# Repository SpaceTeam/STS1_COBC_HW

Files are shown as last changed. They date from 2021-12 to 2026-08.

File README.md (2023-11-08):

# COBC Hardware

This is a github repo for the COBC (communication and on-board computer) project of SpaceTeamSat1 (STS1) CubeSat mission of the TU Wien Space Team.

# Licensing
STS1_COBC_HW (c) by TU Wien Space Team

STS1_COBC_HW is licensed under a
Creative Commons Attribution 4.0 International License.

You should have received a copy of the license along with this
work. If not, see <https://creativecommons.org/licenses/by/4.0/>.

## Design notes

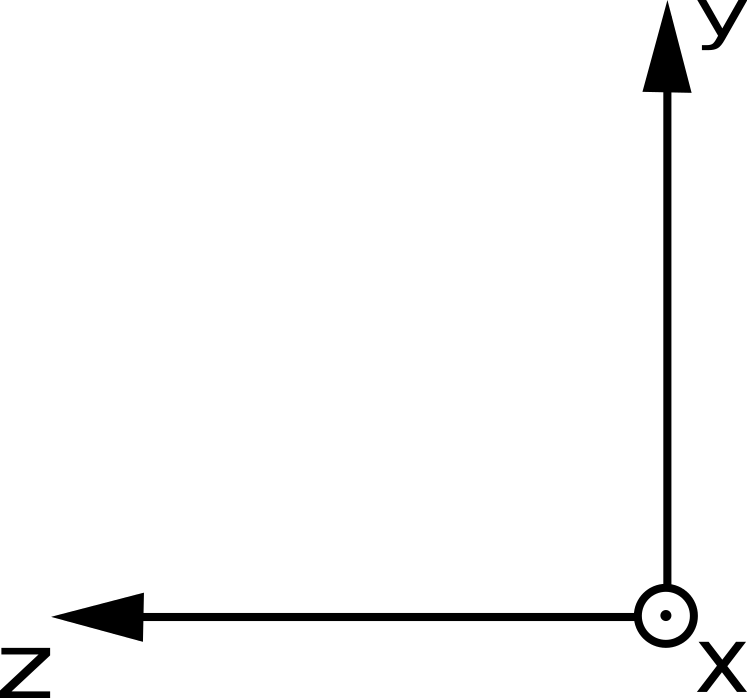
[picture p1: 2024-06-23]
coordinatesystem.png

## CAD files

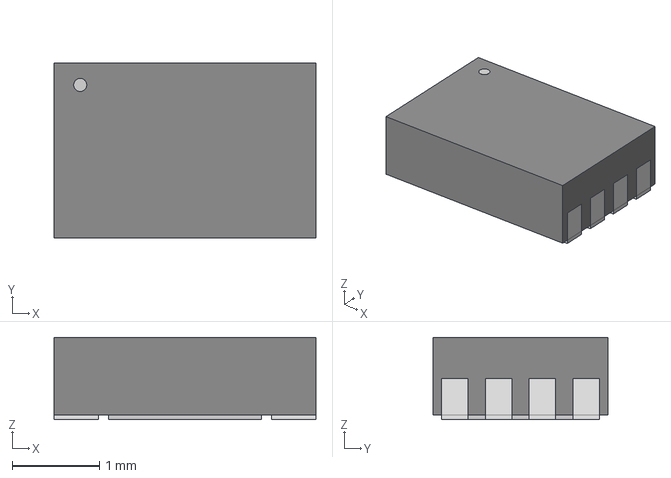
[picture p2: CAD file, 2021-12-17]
Parts/2021-11-17_15-36-51/STEP/DFN8_2x3MC_MCH.step
3.00 x 2.01 x 0.942 mm

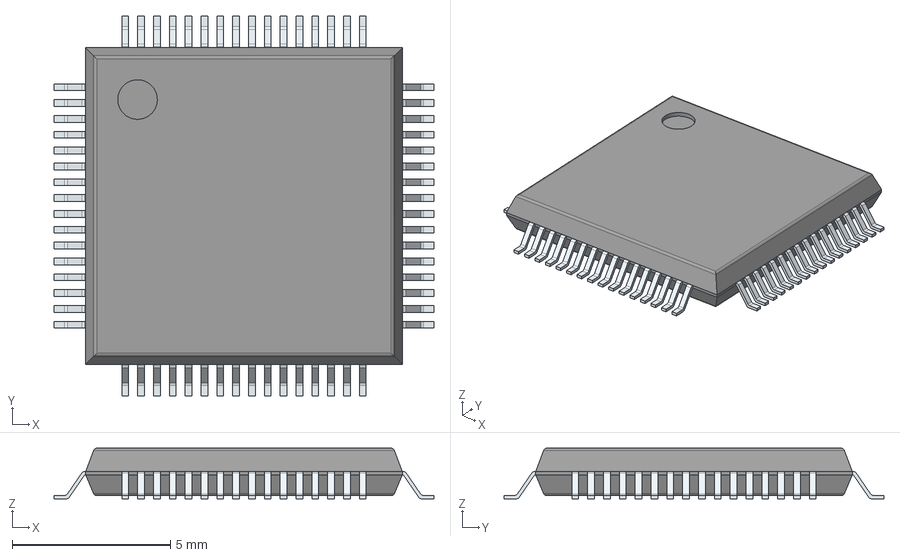
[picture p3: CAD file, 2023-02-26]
Parts/STM32F411RET6TR/3D/STM32F411RET6TR.stp
12.0 x 12.0 x 1.60 mm
PinsArrayLR
PinsArrayTB

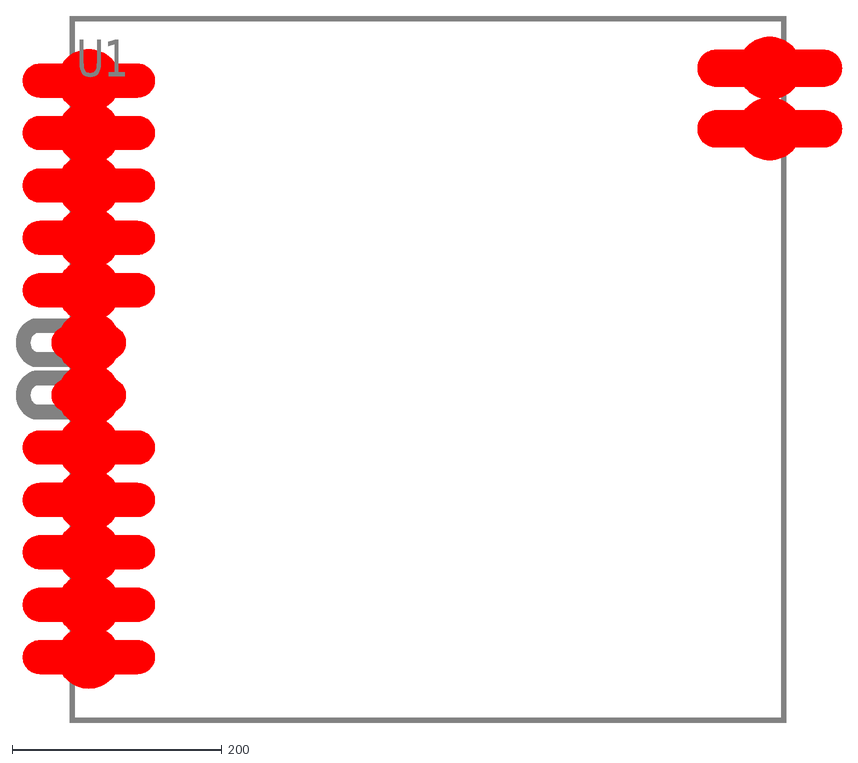
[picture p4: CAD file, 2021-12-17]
Parts/小功率封装.dxf
U1

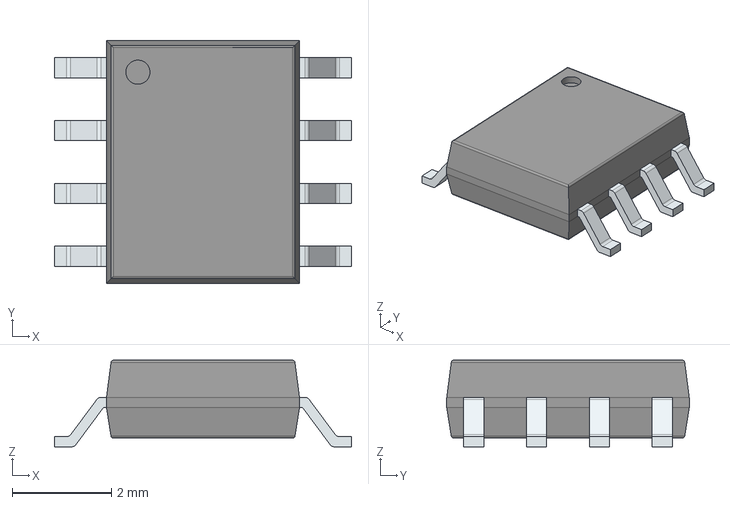
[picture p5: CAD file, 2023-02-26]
SpaceteamLib/MCP1725-3302E_SN/3D/MCP1725-3302E_SN.stp
6.00 x 4.90 x 1.75 mm
PinsArrayLR

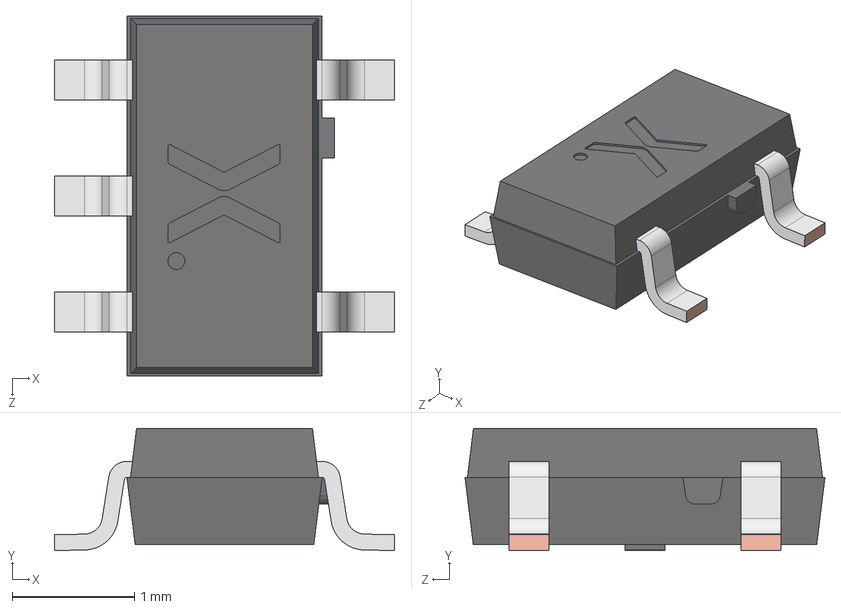
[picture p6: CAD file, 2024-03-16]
STSLib/74LVC1G32GV_125.stp
2.79 x 1.00 x 2.95 mm
SOT753 Lower mold body
SOT753 Lead x 5
SOT753 Upper mold body

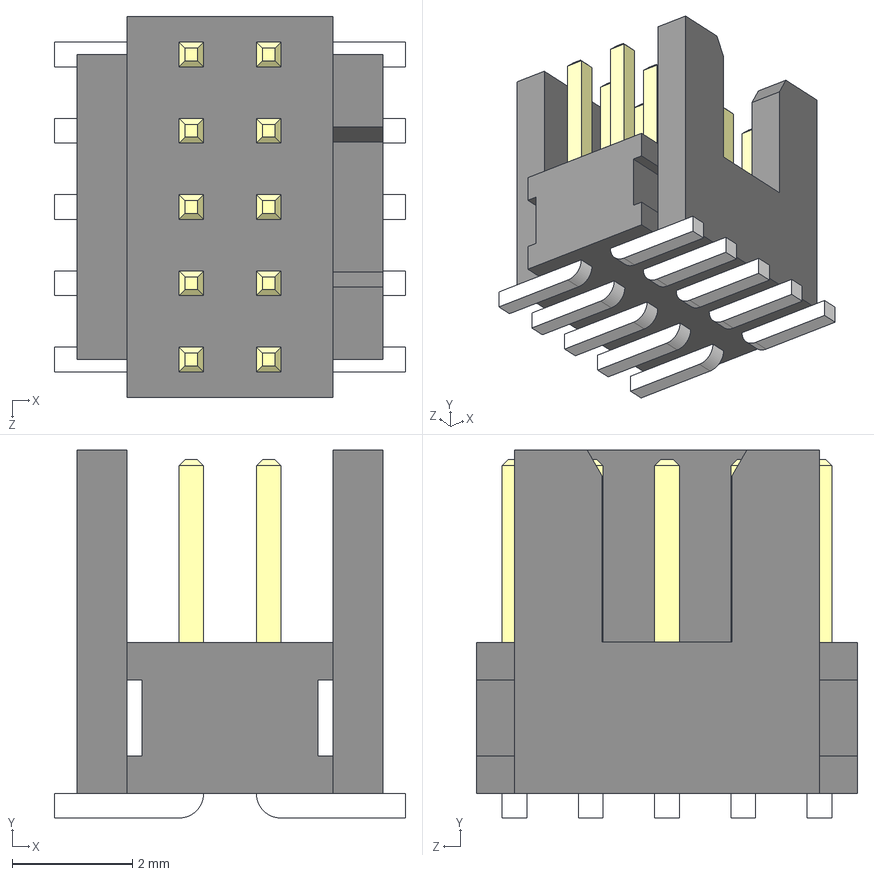
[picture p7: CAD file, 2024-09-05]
SWD-Adapter/3D-models/FTSH-105-01-L-DV-K.stp
5.85 x 6.13 x 6.35 mm

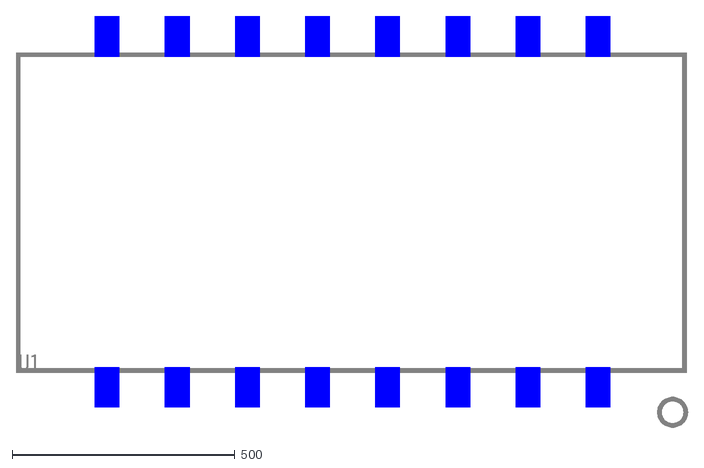
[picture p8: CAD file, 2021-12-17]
Parts/F27 F30 package 2018.dxf
U1

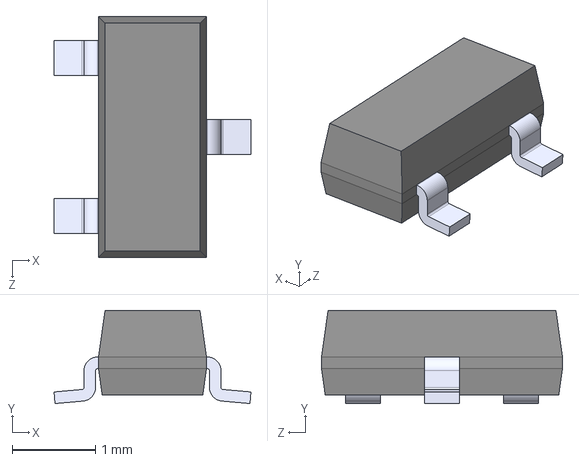
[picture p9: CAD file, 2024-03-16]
STSLib/MCP130T-300I_TT.step
2.37 x 1.12 x 2.90 mm

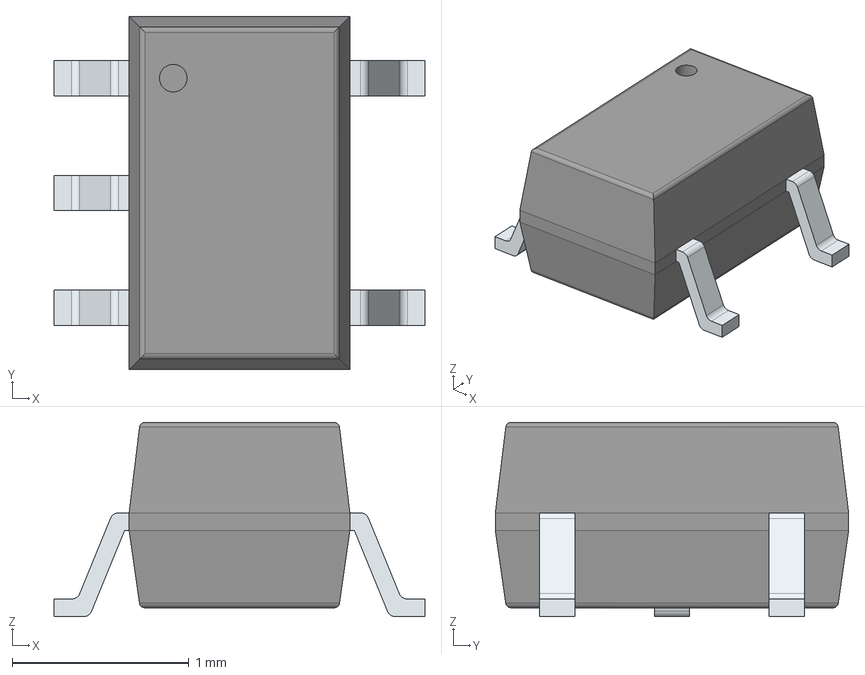
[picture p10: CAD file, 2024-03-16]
STSLib/NC7SZ32P5X-F22057.stp
2.10 x 2.00 x 1.10 mm
PinsArrayL
PinsArrayR

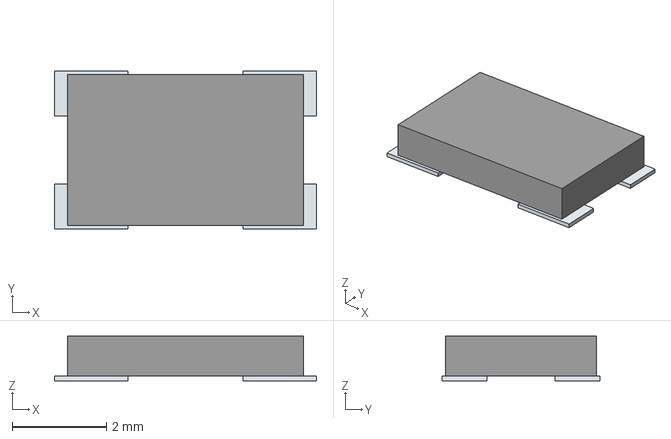
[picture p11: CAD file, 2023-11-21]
STSLib/405C35B12M00000.stp
5.56 x 3.36 x 0.95 mm
Pins

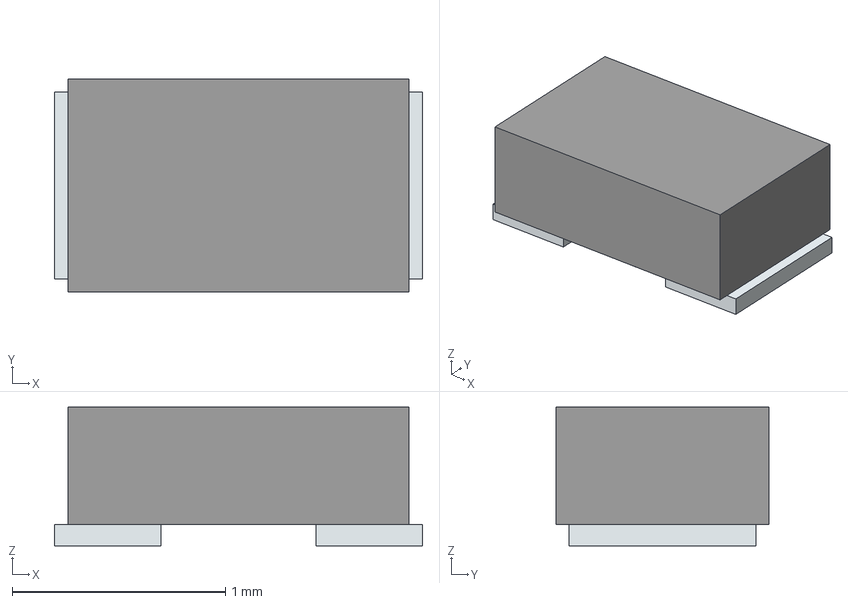
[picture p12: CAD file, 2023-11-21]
STSLib/UCLAMP0871P.TNT.stp
1.73 x 1.00 x 0.65 mm
Pins

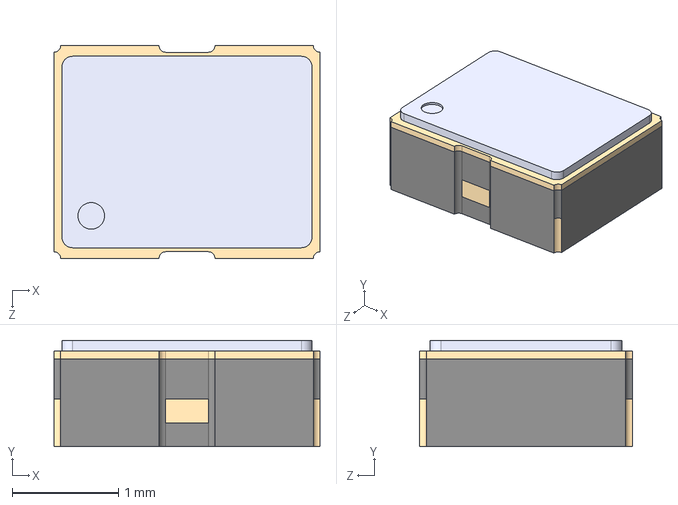
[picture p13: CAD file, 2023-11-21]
STSLib/ECS-2033-250-BN.step
2.50 x 1.00 x 2.00 mm

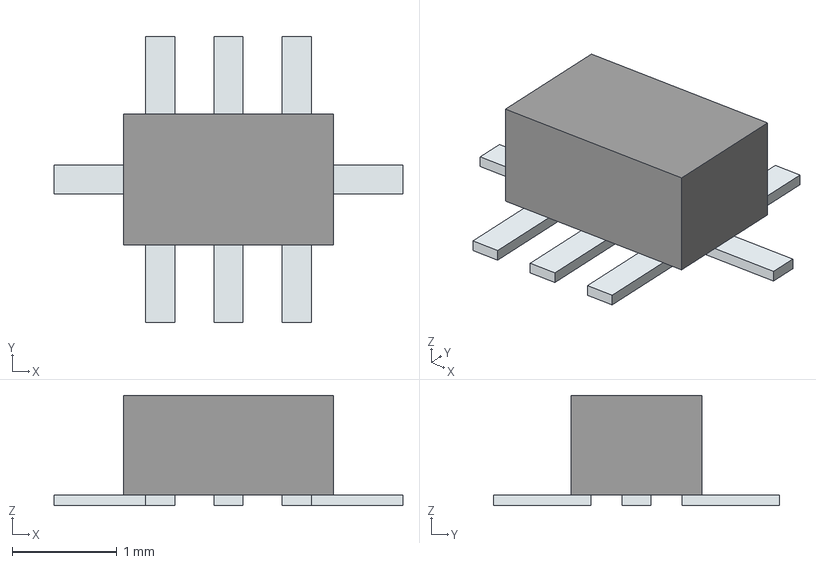
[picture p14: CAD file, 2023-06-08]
STSLib/LFCG-490+.stp
3.33 x 2.73 x 1.05 mm
Pins

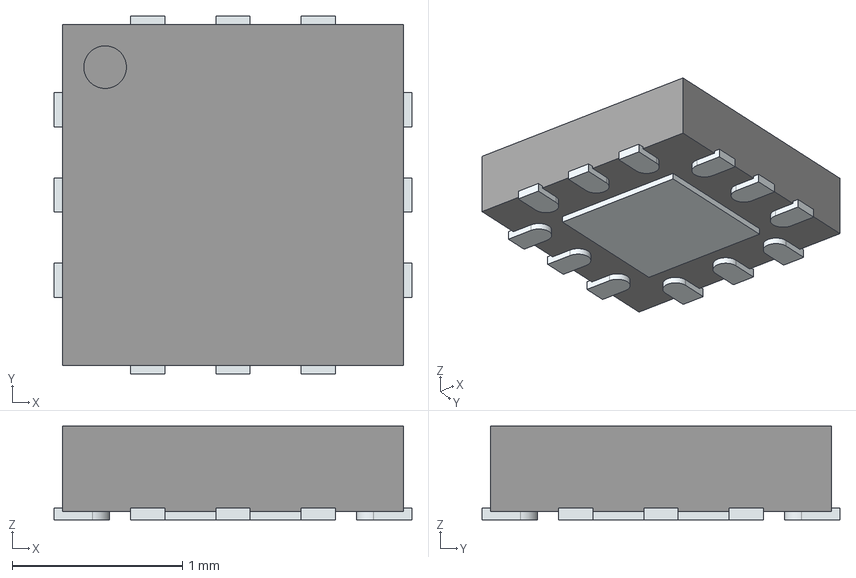
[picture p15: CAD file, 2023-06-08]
STSLib/F2972NEGK8.stp
2.10 x 2.10 x 0.55 mm
ThermalPin
PinsArrayLR
PinsArrayTB

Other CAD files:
Parts/si4463_Vc2/master/master.obj
Parts/si4463_Vc2/slaver/startup.obj
Parts/si4463_Vc2/master/startup.obj
Parts/si4463_Vc2/slaver/slaver.obj
Parts/STM32F411RET6TR/3D/STM32F411RET6TR.stl
Parts/STM32F411RET6TR/Allegro/qfp50p1200x1200x160-64n.psm
Parts/STM32F411RET6TR/DEHDL/stm32f411ret6tr/chips/chips.prt
STSLib/61612002121503.stp
STSLib/CY15B108QN-40SXI.stp
STSLib/FPF2701MPX.stp
STSLib/MC74HC4538ADG.stp
STSLib/MCP1725-3302E_MC.stp
STSLib/MP28167GQ-P.stp
STSLib/STM32F411RET6TR.stl
STSLib/Si4463-C2A-GM.stp
STSLib/TQP3M9036.stp
STSLib/W25Q01JVZEIQ.stp
SpaceteamLib/MCP1725-3302E_SN/3D/MCP1725-3302E_SN.stl
SpaceteamLib/MCP1725-3302E_SN/Allegro/soic127p600x175-8n.psm
SpaceteamLib/MCP1725-3302E_SN/DEHDL/mcp1725_3302e_sn/chips/chips.prt

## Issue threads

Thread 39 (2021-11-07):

add latch up protection for stm and rf modules

XDjackieXD, 2021-11-07:
we need separate latch up protection for the stm and the rf modules.
the stm should be able to disable said protection for the rf modules, as they draw *way* more power during transmit (so we disable their latch up protection during TX and enable it again after we are done sending)

asmolyanyuk, 2024-03-17:
Added two separate latch-up protection circuits.
The schematics employed is from the page 149 (164 pdf) of "Project solutions for low-cost space missions" [thesis](https://zerorobotics.polito.it/app/uploads/2019/04/thesis-1.pdf).

Closed 2024-03-17.

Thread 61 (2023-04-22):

RF temp sensor

WagnerDavid, 2023-04-22:
We should place a temperature sensor next to the RF chip, so we can figure out if something went wrong and react to it - send less or so

Jakob: "if you tell me at which adc input from the stm then gladly. I would just suggest the tmp36. it is low power, quite accurate and has a linear output." Analog as it is more reliable.

asmolyanyuk, 2024-03-17:
A temperature sensor is placed next to the RF chip, tmp36, and internal ADC of STM will be used to probe it (pin PC0).

Closed 2024-03-17.

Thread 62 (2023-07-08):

Add a separate 3.3 V LDO for RF part

asmolyanyuk, 2023-07-08:
We need to have a separate LDO on the 3.3 V rail of RF subsystem.

asmolyanyuk, 2024-03-17:
A separate LDO for RF subsystem is added.

Closed 2024-03-17.

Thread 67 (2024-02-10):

Add series resistors to all stm pins to prevent short circuits from destroying the stm

XDjackieXD, 2024-02-10:

asmolyanyuk, 2024-03-17:
Added 100 Ohm resistor to EDU_Boot_Pin line.

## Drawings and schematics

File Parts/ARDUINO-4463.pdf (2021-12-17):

D

6 | 5 | 4 | 3 | 2 | 1

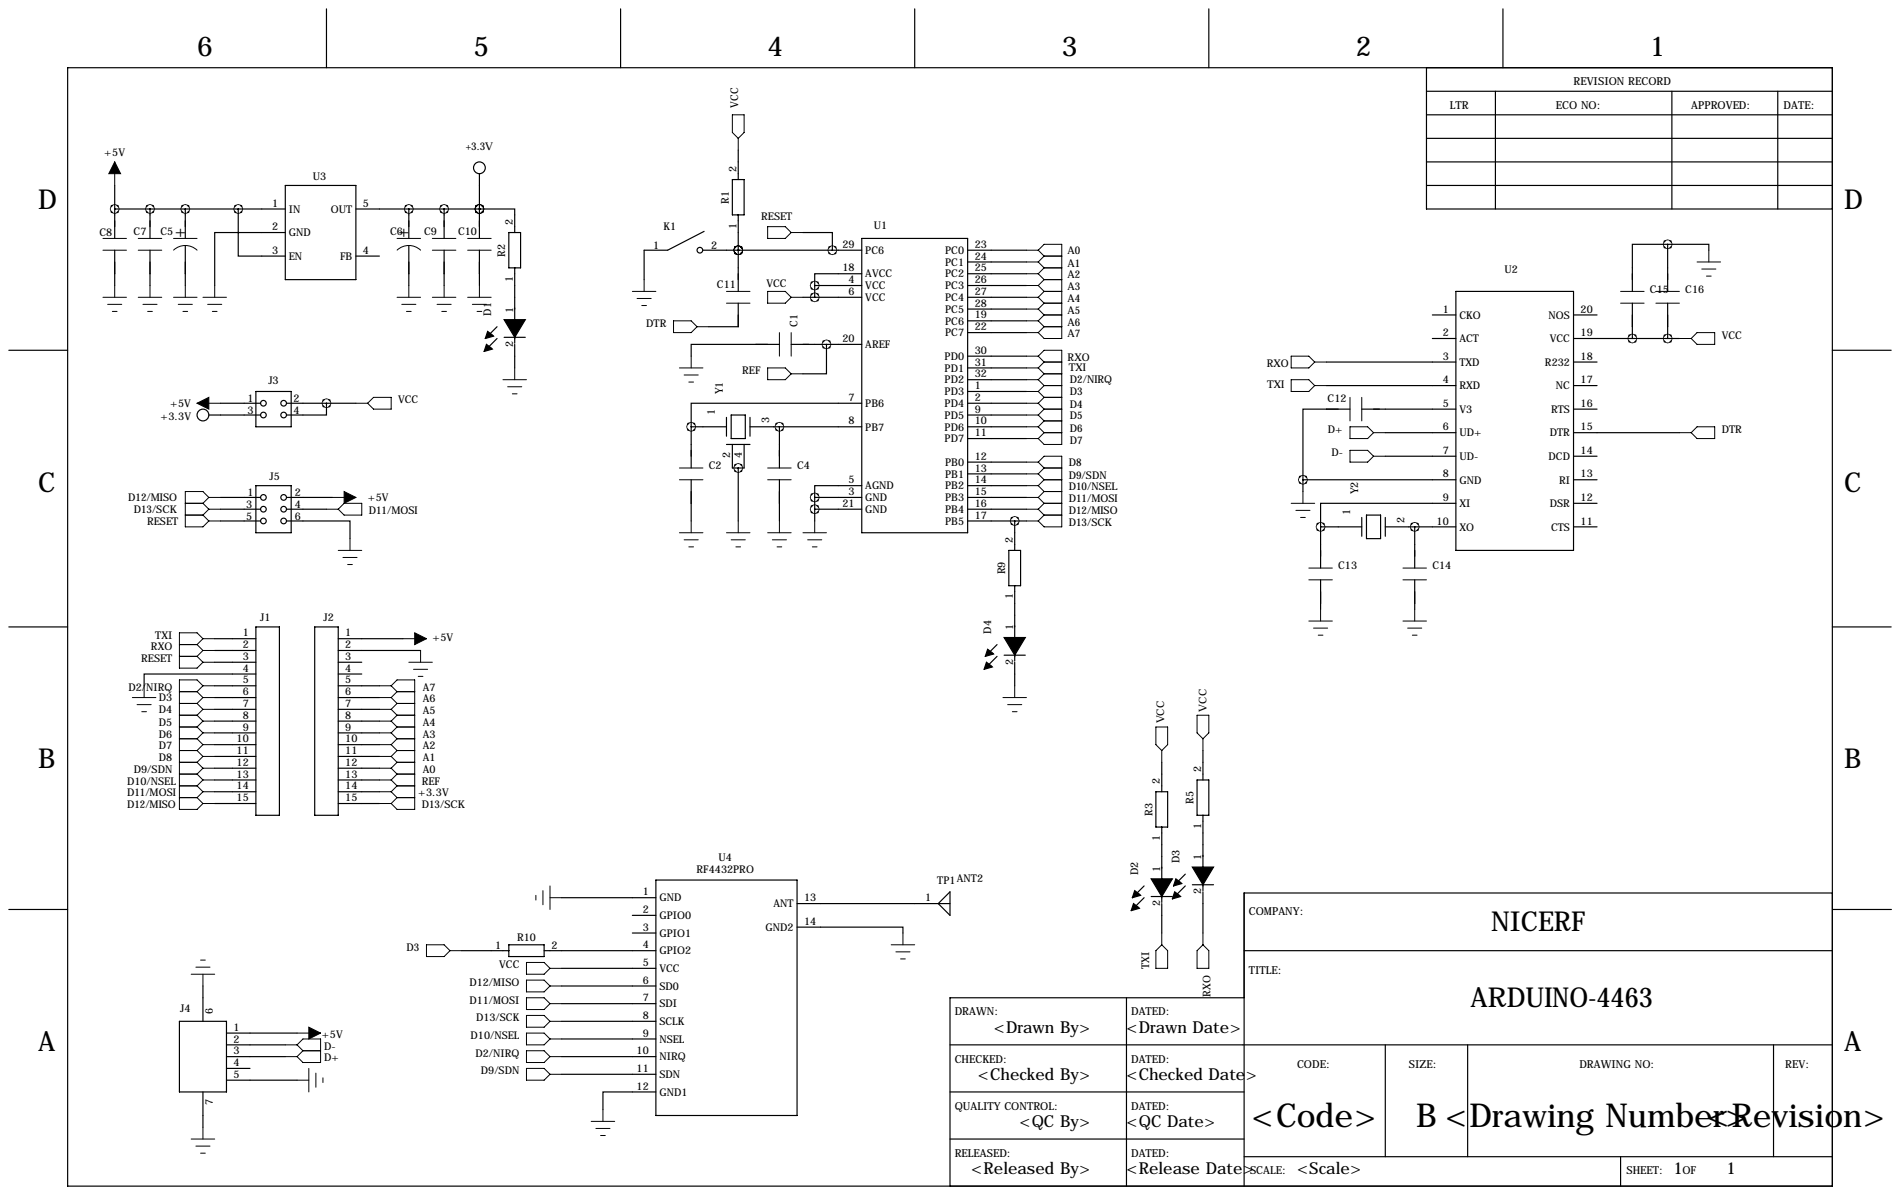
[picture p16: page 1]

+3.3V | REVISION RECORD

LTR | ECO NO: | APPROVED: | DATE:

QUALITY CONTROL: <QC By> | DATED: <QC Date>

RELEASED: <Released By> | DATED:

<Scale> SCALE: | 1 1 SHEET: OF

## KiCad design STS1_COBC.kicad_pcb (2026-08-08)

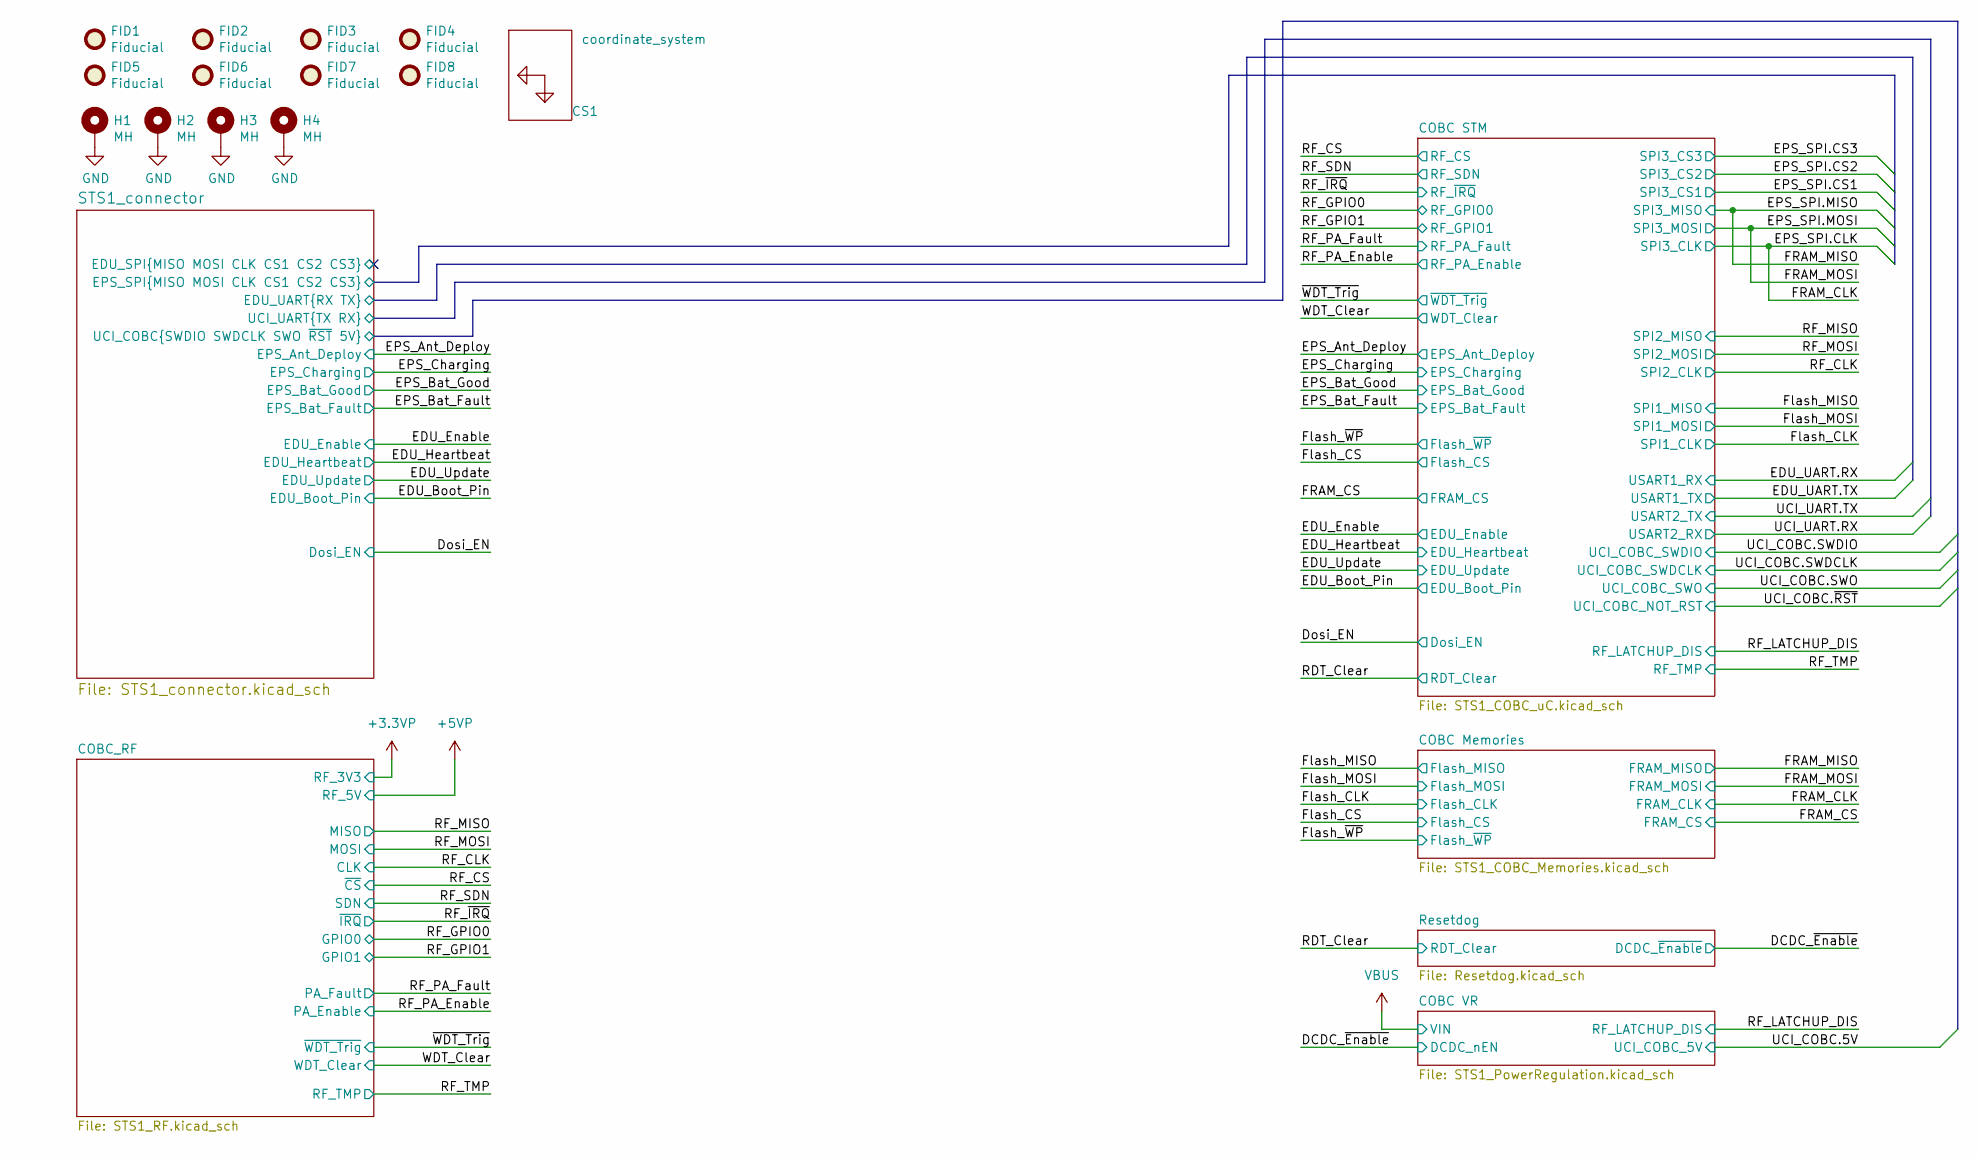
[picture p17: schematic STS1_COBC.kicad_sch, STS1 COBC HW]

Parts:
CS1: coordinate_system; Coordinates
FID1, FID2, FID3, FID4, FID5, FID6, FID7, FID8: Fiducial; Fiducial_0.75mm_Mask1.5mm
H1, H2, H3, H4: MH; MountingHole_4.3mm_M4_Pad_Via

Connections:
GND: H1.1 (1_1), H2.1 (1_1), H3.1 (1_1), H4.1 (1_1); also elsewhere on the board

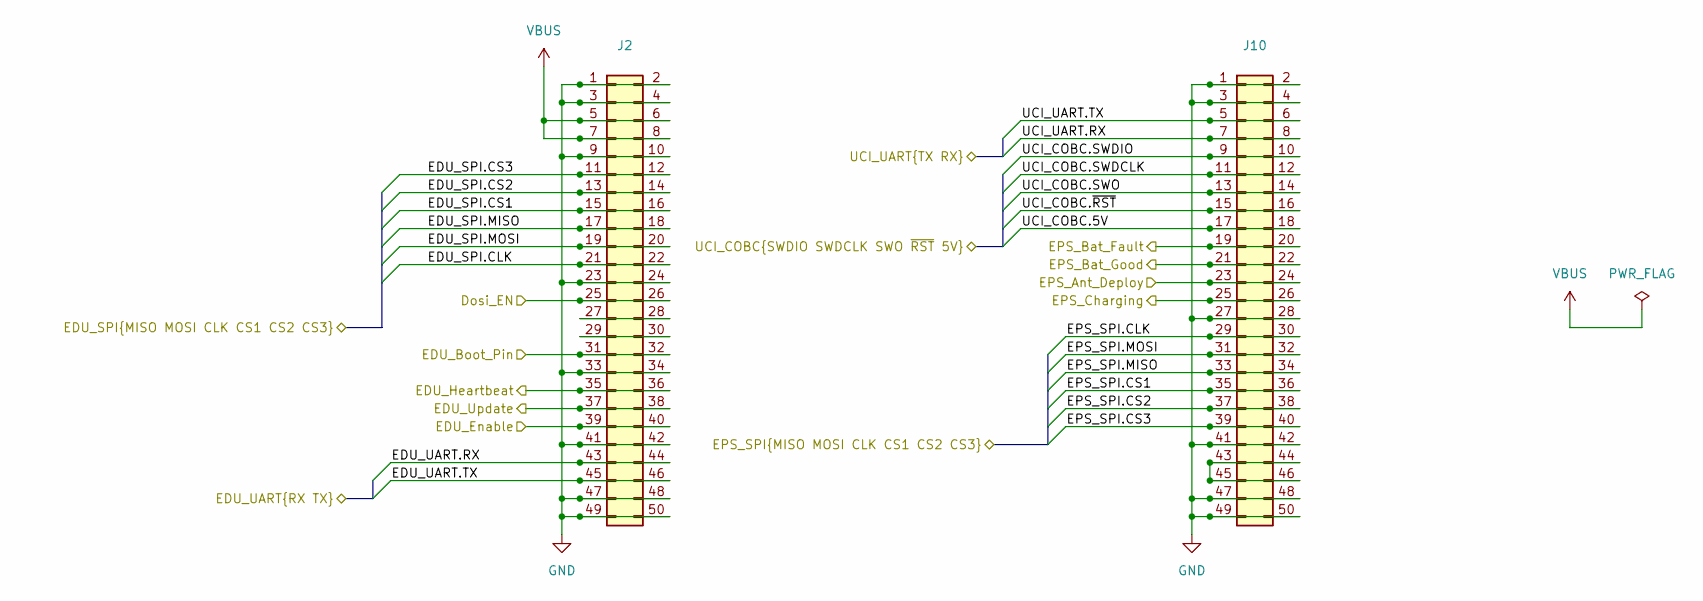
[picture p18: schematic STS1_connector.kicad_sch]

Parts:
J2, J10: PinSocket_2x25_P2.00mm_Vertical

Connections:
/Dosi_EN: J2.25, J2.26; also elsewhere on the board
/EDU_Boot_Pin: J2.31, J2.32; also elsewhere on the board
/EDU_Enable: J2.39, J2.40; also elsewhere on the board
/EDU_Heartbeat: J2.35, J2.36; also elsewhere on the board
/EDU_Update: J2.37, J2.38; also elsewhere on the board
/EPS_Ant_Deploy: J10.23, J10.24; also elsewhere on the board
/EPS_Bat_Fault: J10.19, J10.20; also elsewhere on the board
/EPS_Bat_Good: J10.21, J10.22; also elsewhere on the board
/EPS_Charging: J10.25, J10.26; also elsewhere on the board
/STS1_connector/EDU_SPI.CLK: J2.21, J2.22
/STS1_connector/EDU_SPI.CS1: J2.15, J2.16
/STS1_connector/EDU_SPI.CS2: J2.13, J2.14
/STS1_connector/EDU_SPI.CS3: J2.11, J2.12
/STS1_connector/EDU_SPI.MISO: J2.17, J2.18
/STS1_connector/EDU_SPI.MOSI: J2.19, J2.20
/STS1_connector/EDU_UART.RX: J2.43, J2.44; also elsewhere on the board
/STS1_connector/EDU_UART.TX: J2.45, J2.46; also elsewhere on the board
/STS1_connector/EPS_SPI.CLK: J10.29, J10.30; also elsewhere on the board
/STS1_connector/EPS_SPI.CS1: J10.35, J10.36; also elsewhere on the board
/STS1_connector/EPS_SPI.CS2: J10.37, J10.38; also elsewhere on the board
/STS1_connector/EPS_SPI.CS3: J10.39, J10.40; also elsewhere on the board
/STS1_connector/EPS_SPI.MISO: J10.33, J10.34; also elsewhere on the board
/STS1_connector/EPS_SPI.MOSI: J10.31, J10.32; also elsewhere on the board
/STS1_connector/UCI_COBC.5V: J10.17, J10.18; also elsewhere on the board
/STS1_connector/UCI_COBC.SWDCLK: J10.11, J10.12; also elsewhere on the board
/STS1_connector/UCI_COBC.SWDIO: J10.9, J10.10; also elsewhere on the board
/STS1_connector/UCI_COBC.SWO: J10.13, J10.14; also elsewhere on the board
/STS1_connector/UCI_COBC.~RST: J10.15, J10.16; also elsewhere on the board
/STS1_connector/UCI_UART.RX: J10.7, J10.8; also elsewhere on the board
/STS1_connector/UCI_UART.TX: J10.5, J10.6; also elsewhere on the board
GND: J2.1, J2.2, J2.3, J2.4, J2.9, J2.10, J2.23, J2.24, J2.33, J2.34, J2.41, J2.42, J2.47, J2.48, J2.49, J2.50, J10.1, J10.2, J10.3, J10.4, J10.27, J10.28, J10.41, J10.42, J10.47, J10.48, J10.49, J10.50; also elsewhere on the board
unnamed: J2.27, J2.28
unnamed: J2.29, J2.30
unnamed: J10.43, J10.44, J10.45, J10.46
VBUS: J2.5, J2.6, J2.7, J2.8; also elsewhere on the board

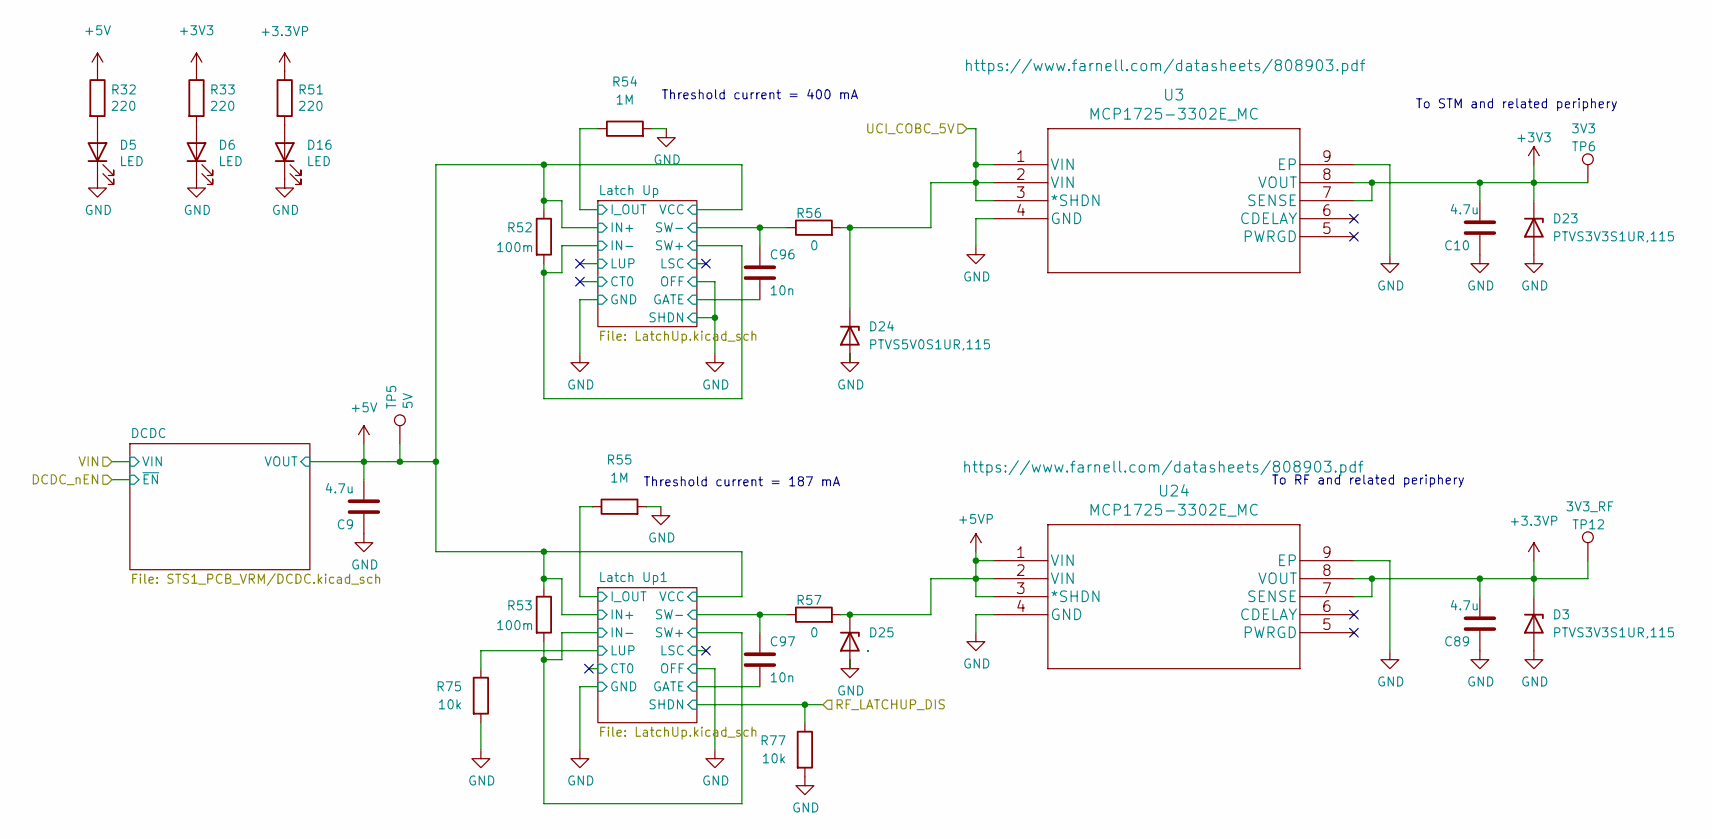
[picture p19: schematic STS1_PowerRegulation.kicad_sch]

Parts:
C9, C10, C89: 4.7u; C_0603_1608Metric; Manufacturer_Part_Number CGA3E1X5R0J475KT0Y0E; JLCPCB Part # C338087
C96, C97: 10n; C_0603_1608Metric; Manufacturer_Part_Number C0603C103M5RACAUTO; JLCPCB Part # C2180616
D3, D23: PTVS3V3S1UR,115; D_SOD-123; Manufacturer_Part_Number PTVS3V3S1UR,115; JLCPCB Part # C183521
D5, D6, D16: LED; LED_0805_2012Metric; Manufacturer_Part_Number BL-HGE35A-AV-TRB; JLCPCB Part # C165984
D24, D25: PTVS5V0S1UR,115; D_SOD-123; Manufacturer_Part_Number PTVS5V0S1UR,115; JLCPCB Part # C478011
R32, R33, R51: 220; R_0603_1608Metric; Manufacturer_Part_Number ERJ-H3EF2200V; JLCPCB Part # C4257599
R52, R53: 100m; R_0603_1608Metric; Manufacturer_Part_Number RCWL0603R100JQEA; JLCPCB Part # C1698656
R54, R55: 1M; R_0603_1608Metric; Manufacturer_Part_Number MR06X1004FTL
R56, R57: 0; R_0603_1608Metric; Manufacturer_Part_Number ERJ-H3G0R00V; JLCPCB Part # C4117710
R75, R77: 10k; R_0603_1608Metric; Manufacturer_Part_Number ERJ-H3EF1002V; JLCPCB Part # C4297913
TP5: 5V; STS1_Testpoint
TP6: 3V3; STS1_Testpoint
TP12: 3V3_RF; STS1_Testpoint
U3, U24: MCP1725-3302E_MC; MCP1725-3302E&slash_MC; Manufacturer_Part_Number MCP1725-3302E/MC; JLCPCB Part # C635002

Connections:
+3.3VP: C89.2, D3.1 (K), R51.1, TP12.1 (1_1), U24.7 (SENSE), U24.8 (VOUT); also elsewhere on the board
+3V3: C10.2, D23.1 (K), R33.1, TP6.1 (1_1), U3.7 (SENSE), U3.8 (VOUT); also elsewhere on the board
+5V: C9.2, R32.1, R52.1, R53.1, TP5.1 (1_1); also elsewhere on the board
+5VP: D25.1 (K), R57.2, U24.1 (VIN), U24.2 (VIN), U24.3 (*SHDN); also elsewhere on the board
/COBC VR/Latch Up1/GATE: C97.2; also elsewhere on the board
/COBC VR/Latch Up1/IN-: R53.2; also elsewhere on the board
/COBC VR/Latch Up1/I_OUT: R55.1; also elsewhere on the board
/COBC VR/Latch Up1/LUP: R75.1; also elsewhere on the board
/COBC VR/Latch Up1/SW-: C97.1, R57.1; also elsewhere on the board
/COBC VR/Latch Up/GATE: C96.2; also elsewhere on the board
/COBC VR/Latch Up/IN-: R52.2; also elsewhere on the board
/COBC VR/Latch Up/I_OUT: R54.1; also elsewhere on the board
/COBC VR/Latch Up/SW-: C96.1, R56.1; also elsewhere on the board
/RF_LATCHUP_DIS: R77.1; also elsewhere on the board
/STS1_connector/UCI_COBC.5V: D24.1 (K), R56.2, U3.1 (VIN), U3.2 (VIN), U3.3 (*SHDN); also elsewhere on the board
GND: C9.1, C10.1, C89.1, D3.2 (A), D5.1 (K), D6.1 (K), D16.1 (K), D23.2 (A), D24.2 (A), D25.2 (A), R54.2, R55.2, R75.2, R77.2, U3.4 (GND), U3.9 (EP), U24.4 (GND), U24.9 (EP); also elsewhere on the board
unnamed: D5.2 (A), R32.2
unnamed: D6.2 (A), R33.2
unnamed: D16.2 (A), R51.2

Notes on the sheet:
Threshold current = 400 mA
Threshold current = 187 mA
To RF and related periphery
To STM and related periphery

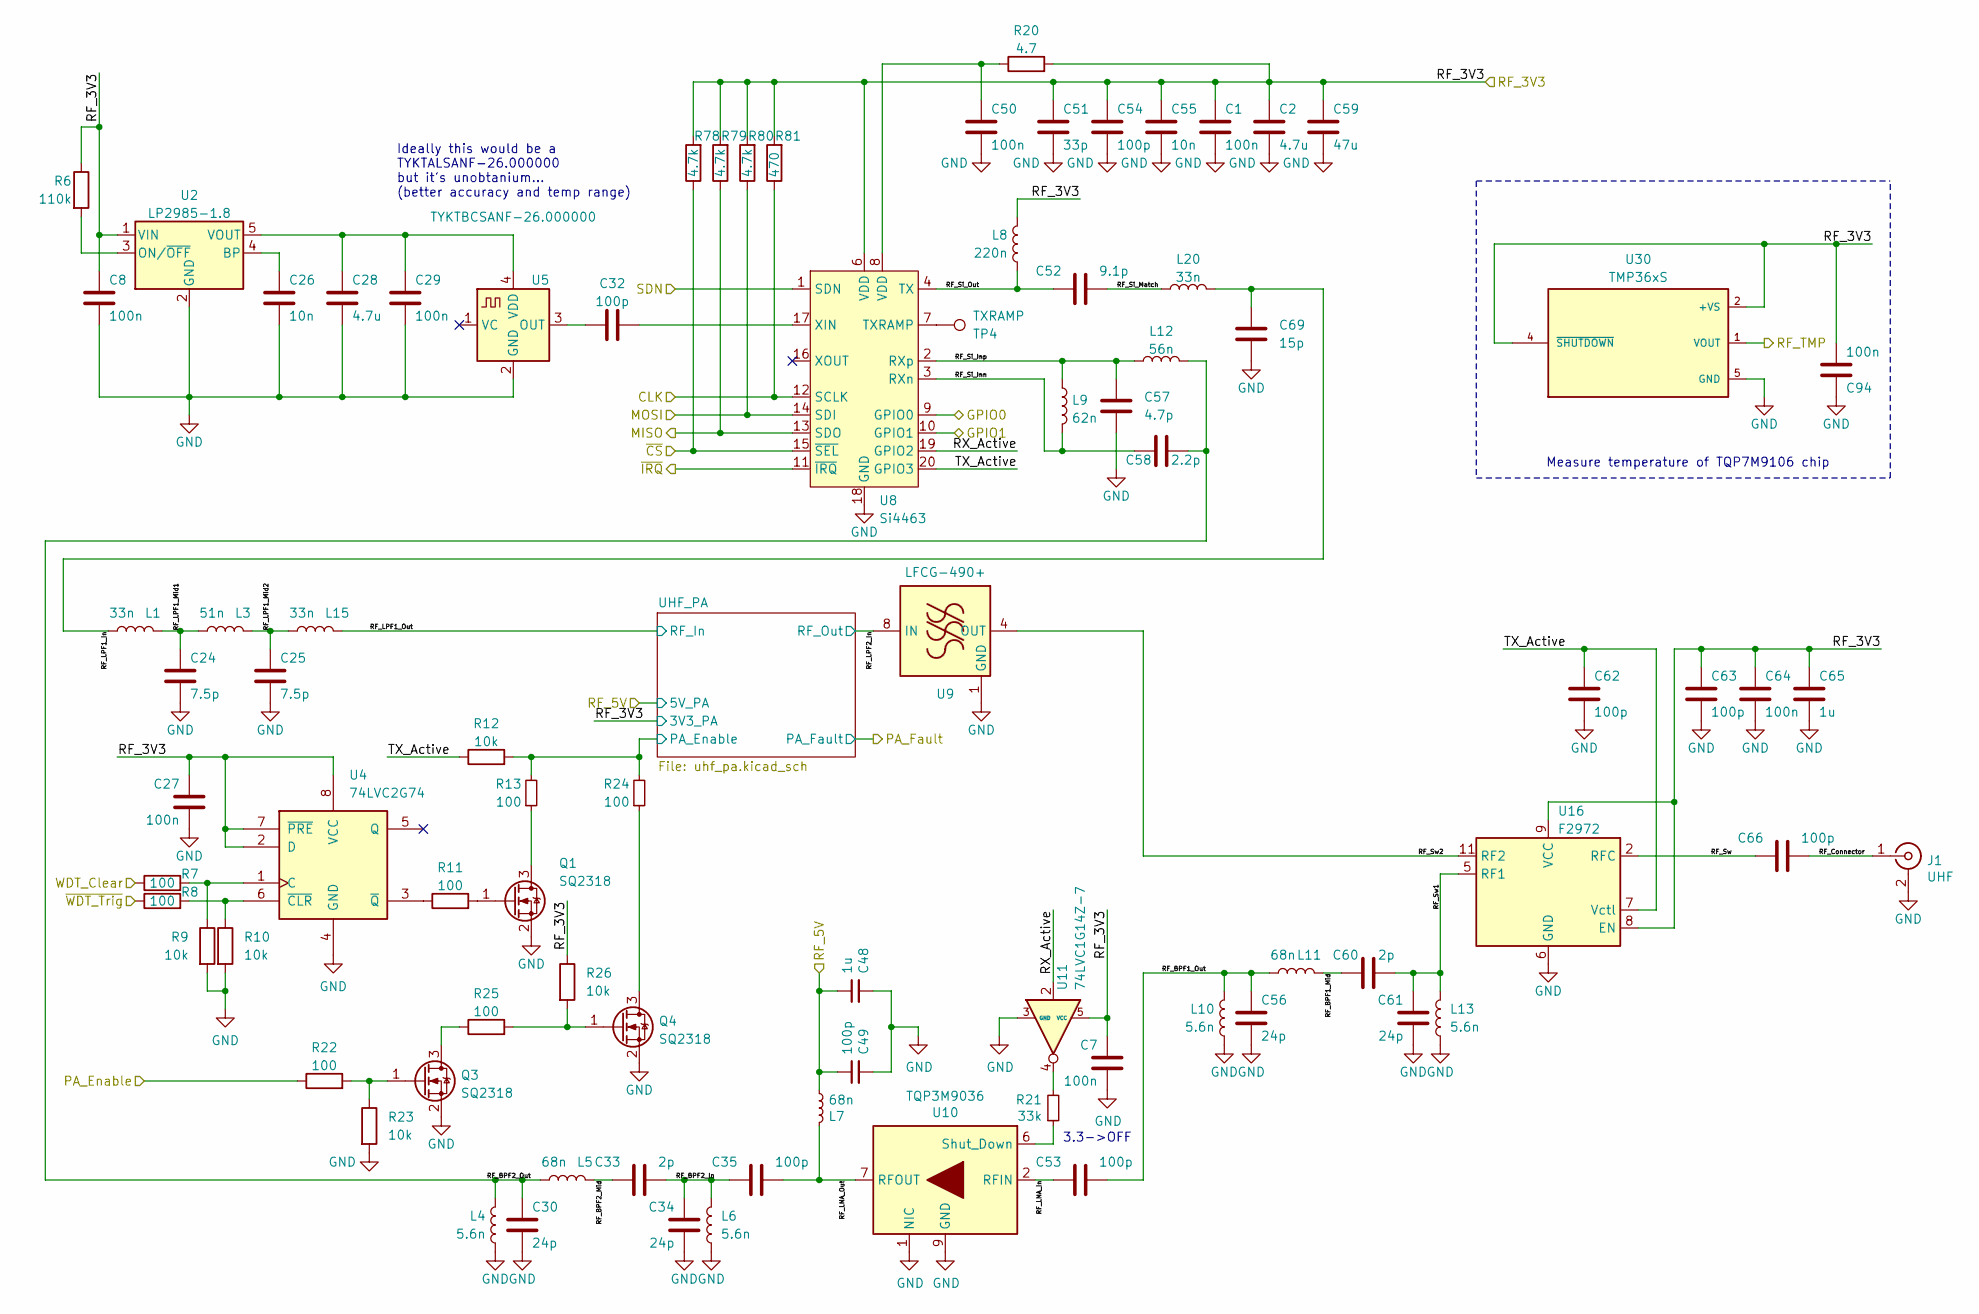
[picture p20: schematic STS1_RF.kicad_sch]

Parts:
C1, C7, C8, C27, C29, C50, C64: 100n; C_0805_2012Metric; Manufacturer_Part_Number C0805C104K1RACAUTO; JLCPCB Part # C141125
C2, C28: 4.7u; C_0805_2012Metric; Manufacturer_Part_Number C0805C475K4RACAUTO; JLCPCB Part # C599948
C24, C25: 7.5p; C_0402_1005Metric; Manufacturer_Part_Number VJ0402D7R5CXAAJHT; JLCPCB Part # C3864905
C26, C55: 10n; C_0805_2012Metric; Manufacturer_Part_Number C0805C103K8RACAUTO; JLCPCB Part # C561833
C30, C34, C56, C61: 24p; C_0402_1005Metric; Manufacturer_Part_Number UMK105CG240JV-F; JLCPCB Part # C3833393
C32, C35, C53, C54, C62, C63, C66: 100p; C_0402_1005Metric; Manufacturer_Part_Number UMK105CG101JV-F; JLCPCB Part # C386123
C33, C60: 2p; C_0402_1005Metric; Manufacturer_Part_Number GRM1555C1H2R0CA01D; JLCPCB Part # C76962
C48: 1u; C_0805_2012Metric; PartNumber C0402C105K8PAC7411; JLCPCB Part # C3874210
C49: 100p; C_0402_1005Metric; PartNumber CBR04C101J3GAC; JLCPCB Part # C386123
C51: 33p; C_0402_1005Metric; Manufacturer_Part_Number CL05C330JB5NNNC; JLCPCB Part # C70465
C52: 9.1p; C_0402_1005Metric; Manufacturer_Part_Number RF15N9R1B500CT; JLCPCB Part # C3908063
C57: 4.7p; C_0402_1005Metric; Manufacturer_Part_Number 885392005012; JLCPCB Part # C5534411
C58: 2.2p; C_0402_1005Metric; Manufacturer_Part_Number RF15N2R2B500CT; JLCPCB Part # C172819
C59: 47u; C_0805_2012Metric; Manufacturer_Part_Number T58W9476M6R3C0200; JLCPCB Part # C3008877
C65: 1u; C_0805_2012Metric; Manufacturer_Part_Number C0805C105K5RACAUTO; JLCPCB Part # C3874210
C69: 15p; C_0402_1005Metric; Manufacturer_Part_Number CC0402FRNPO9BN150; JLCPCB Part # C326803
C94: 100n; C_0603_1608Metric; Manufacturer_Part_Number C0603C104K5RACAUTO; JLCPCB Part # C129621
J1: UHF; SMB_Jack_Vertical; Manufacturer_Part_Number 61612002121503; JLCPCB Part # C6095037
L1, L15, L20: 33n; L_0402_1005Metric; PartNumber LQW15AN33NJ8ZD; JLCPCB Part # C2043918
L3: 51n; L_0402_1005Metric; PartNumber LQW15AN51NG80D
L4, L6, L10, L13: 5.6n; L_0402_1005Metric; PartNumber LQW15AN5N6C1ZD
L5, L7, L11: 68n; L_0402_1005Metric; PartNumber LQW15AN68NJ0ZD; JLCPCB Part # C2049784
L8: 220n; L_0402_1005Metric; PartNumber LQW15CNR22J10D; JLCPCB Part # C341690
L9: 62n; L_0402_1005Metric; PartNumber LQW15AN62NJ0ZD
L12: 56n; L_0402_1005Metric; PartNumber LQW15AN56NH0ZD
Q1, Q3, Q4: SQ2318; SOT-23; Manufacturer_Part_Number SQ2318AES-T1_BE3; JLCPCB Part # C3280170
R6: 110k; R_0603_1608Metric; Manufacturer_Part_Number ERJ-H3EF1103V; JLCPCB Part # C4176290
R7, R8, R11, R13, R22, R24, R25: 100; R_0603_1608Metric; Manufacturer_Part_Number CRS0603AFX-1000ELF; JLCPCB Part # C2074896
R9, R10, R12, R23, R26: 10k; R_0603_1608Metric; Manufacturer_Part_Number ERJ-H3EF1002V; JLCPCB Part # C4297913
R20: 4.7; R_0603_1608Metric; Manufacturer_Part_Number CHP0603QFW-4R70ELF
R21: 33k; R_0603_1608Metric; Manufacturer_Part_Number ERJ-H3EF3302V; JLCPCB Part # C4220470
R78, R79, R80: 4.7k; R_0603_1608Metric; Manufacturer_Part_Number ERJ-H3EF4701V; JLCPCB Part # C4343266
R81: 470; R_0603_1608Metric; Manufacturer_Part_Number ERJ-3EKF4700V; JLCPCB Part # C169259
TP4: TXRAMP; STS1_Testpoint
U2: LP2985-1.8; SOT-23-5; Manufacturer_Part_Number LP2985-18DBVRE4; JLCPCB Part # C3752498
U4: 74LVC2G74; VSSOP-8_2.3x2mm_P0.5mm; Manufacturer_Part_Number SN74LVC2G74DCUTE4; JLCPCB Part # C3826121
U5: TYKTBCSANF-26.000000; Crystal_SMD_2520-4Pin_2.5x2.0mm; Manufacturer_Part_Number TYKTBCSANF-26.000000; JLCPCB Part # C6304737
U8: Si4463; QFN-20-1EP_4x4mm_P0.5mm_EP2.6x2.6mm_ThermalVias; Manufacturer_Part_Number SI4463-C2A-GM; JLCPCB Part # C476202
U9: LFCG-490+; GE0805C-2; PartNumber LFCG-490+; JLCPCB Part # C3034233
U10: TQP3M9036; DFN-8-1EP_2x2mm_P0.5mm_EP0.7x1.6mm_ThermalVias; PartNumber TQP3M9036; JLCPCB Part # C920261
U11: 74LVC1G14Z-7; SOT-553; PartNumber NL17SV04XV5T2G; JLCPCB Part # C3272831
U16: F2972; IDT_NEG-12-1EP_2x2mm_P0.5mm_EP1.1x1.1mm_ThermalVias; Manufacturer_Part_Number F2972NEGK; JLCPCB Part # C1558621
U30: TMP36xS; SOT-23-5; PARTREV H; JLCPCB Part # C129489

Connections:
+3.3VP: C1.1, C2.1, C7.1, C8.1, C27.1, C51.1, C54.1, C55.1, C59.1, C63.1, C64.1, C65.1, C94.2, L8.2, R6.1, R20.2, R26.1, R78.2, R79.2, R80.2, R81.2, U2.1 (VIN), U4.2 (D), U4.7 (~PRE), U4.8 (VCC), U8.6 (VDD), U11.5 (VCC), U16.8 (EN), U16.9 (VCC), U30.2 (+VS), U30.4 (~SHUTDOWN); also elsewhere on the board
+5VP: C48.1, C49.1, L7.2; also elsewhere on the board
/COBC_RF/RF_BPF1_Mid: C60.1, L11.2
/COBC_RF/RF_BPF1_Out: C53.2, C56.1, L10.2, L11.1
/COBC_RF/RF_BPF2_In: C33.2, C34.1, C35.1, L6.2
/COBC_RF/RF_BPF2_Mid: C33.1, L5.2
/COBC_RF/RF_BPF2_Out: C30.1, C58.2, L4.2, L5.1, L12.2
/COBC_RF/RF_Connector: C66.2, J1.1 (In)
/COBC_RF/RF_LNA_In: C53.1, U10.2 (RFIN)
/COBC_RF/RF_LNA_Out: C35.2, L7.1, U10.7 (RFOUT)
/COBC_RF/RF_LPF1_In: C69.1, L1.1, L20.2
/COBC_RF/RF_LPF1_Mid1: C24.1, L1.2, L3.1
/COBC_RF/RF_LPF1_Mid2: C25.1, L3.2, L15.1
/COBC_RF/RF_LPF1_Out: L15.2; also elsewhere on the board
/COBC_RF/RF_LPF2_In: U9.8 (IN); also elsewhere on the board
/COBC_RF/RF_Si_Inn: C58.1, L9.2, U8.3 (RXn)
/COBC_RF/RF_Si_Inp: C57.1, L9.1, L12.1, U8.2 (RXp)
/COBC_RF/RF_Si_Match: C52.2, L20.1
/COBC_RF/RF_Si_Out: C52.1, L8.1, U8.4 (TX)
/COBC_RF/RF_Sw: C66.1, U16.2 (RFC)
/COBC_RF/RF_Sw1: C60.2, C61.1, L13.2, U16.5 (RF1)
/COBC_RF/RF_Sw2: U9.4 (OUT), U16.11 (RF2)
/COBC_RF/RX_Active: U8.19 (GPIO2), U11.2
/COBC_RF/TX_Active: C62.1, R12.1, U8.20 (GPIO3), U16.7 (Vctl)
/COBC_RF/UHF_PA/PA_Enable: R12.2, R13.2, R24.2; also elsewhere on the board
/RF_CLK: R81.1, U8.12 (SCLK); also elsewhere on the board
/RF_CS: R78.1, U8.15 (~SEL); also elsewhere on the board
/RF_GPIO0: U8.9 (GPIO0); also elsewhere on the board
/RF_GPIO1: U8.10 (GPIO1); also elsewhere on the board
/RF_MISO: R79.1, U8.13 (SDO); also elsewhere on the board
/RF_MOSI: R80.1, U8.14 (SDI); also elsewhere on the board
/RF_PA_Enable: R22.1; also elsewhere on the board
/RF_SDN: U8.1 (SDN); also elsewhere on the board
/RF_TMP: U30.1 (VOUT); also elsewhere on the board
/RF_~IRQ: U8.11 (~IRQ); also elsewhere on the board
/WDT_Clear: R7.1; also elsewhere on the board
/~WDT_Trig: R8.1; also elsewhere on the board
GND: C1.2, C2.2, C7.2, C8.2, C24.2, C25.2, C26.2, C27.2, C28.2, C29.2, C30.2, C34.2, C48.2, C49.2, C50.2, C51.2, C54.2, C55.2, C56.2, C57.2, C59.2, C61.2, C62.2, C63.2, C64.2, C65.2, C69.2, C94.1, J1.2 (Ext), L4.1, L6.1, L10.1, L13.1, Q1.2 (S), Q3.2 (S), Q4.2 (S), R9.2, R10.2, R23.2, U2.2 (GND), U4.4 (GND), U5.2 (GND), U8.18 (GND), U8.21 (GND), U9.1 (GND), U9.2 (GND), U9.3 (GND), U9.5 (GND), U9.6 (GND), U9.7 (GND), U10.1 (NIC), U10.3 (NIC), U10.4 (NIC), U10.5 (NIC), U10.8 (NIC), U10.9 (GND), U11.3 (GND), U16.1 (GND), U16.3 (GND), U16.4 (GND), U16.6 (GND), U16.10 (GND), U16.12 (GND), U16.13 (GND), U30.5 (GND); also elsewhere on the board
unnamed: C50.1, R20.1, U8.8 (VDD)
unnamed: Q1.3 (D), R13.1
unnamed: Q1.1 (G), R11.2
unnamed: Q3.3 (D), R25.1
unnamed: Q3.1 (G), R22.2, R23.1
unnamed: Q4.3 (D), R24.1
unnamed: Q4.1 (G), R25.2, R26.2
unnamed: R21.2, U11.4
unnamed: C26.1, U2.4 (BP)
unnamed: R6.2, U2.3 (ON/~OFF)
unnamed: C28.1, C29.1, U2.5 (VOUT), U5.4 (VDD)
unnamed: R7.2, R9.1, U4.1 (C)
unnamed: R8.2, R10.1, U4.6 (~CLR)
unnamed: R11.1, U4.3 (~Q)
unnamed: C32.1, U5.3 (OUT)
unnamed: TP4.1 (1_1), U8.7 (TXRAMP)
unnamed: C32.2, U8.17 (XIN)
unnamed: R21.1, U10.6 (Shut_Down)

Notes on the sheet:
3.3->OFF
Ideally this would be a TYKTALSANF-26.000000 but it's unobtanium... (better accuracy and temp range)
Measure temperature of TQP7M9106 chip

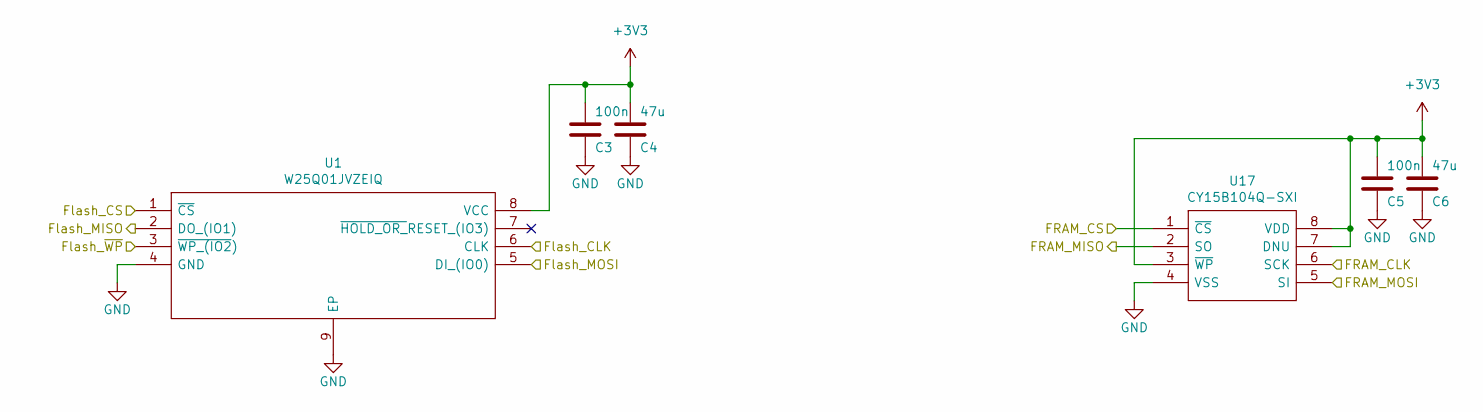
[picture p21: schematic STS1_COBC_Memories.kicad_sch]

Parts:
C3, C5: 100n; C_0603_1608Metric; Manufacturer_Part_Number C0603C104K5RACAUTO; JLCPCB Part # C129621
C4, C6: 47u; C_0603_1608Metric; Manufacturer_Part_Number CL10A476MQ8QRNC; JLCPCB Part # C730416
U1: W25Q01JVZEIQ; SON127P800X600X80-9N-D; Manufacturer_Part_Number W25Q01JVZEIQ; Mouser Part Number 454-W25Q01JVZEIQ
U17: CY15B104Q-SXI; SOIC127P800X203-8N; Manufacturer_Part_Number CY15B104Q-SXI; Mouser Part Number 727-CY15B104Q-SXI

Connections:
+3V3: C3.2, C4.2, C5.2, C6.2, U1.8 (VCC), U17.3 (~WP), U17.7 (DNU), U17.8 (VDD); also elsewhere on the board
/FRAM_CS: U17.1 (~CS); also elsewhere on the board
/Flash_CLK: U1.6 (CLK); also elsewhere on the board
/Flash_CS: U1.1 (~CS); also elsewhere on the board
/Flash_MISO: U1.2 (DO_(IO1)); also elsewhere on the board
/Flash_MOSI: U1.5 (DI_(IO0)); also elsewhere on the board
/Flash_~WP: U1.3 (~WP_(IO2)); also elsewhere on the board
/STS1_connector/EPS_SPI.CLK: U17.6 (SCK); also elsewhere on the board
/STS1_connector/EPS_SPI.MISO: U17.2 (SO); also elsewhere on the board
/STS1_connector/EPS_SPI.MOSI: U17.5 (SI); also elsewhere on the board
GND: C3.1, C4.1, C5.1, C6.1, U1.4 (GND), U1.9 (EP), U17.4 (VSS); also elsewhere on the board

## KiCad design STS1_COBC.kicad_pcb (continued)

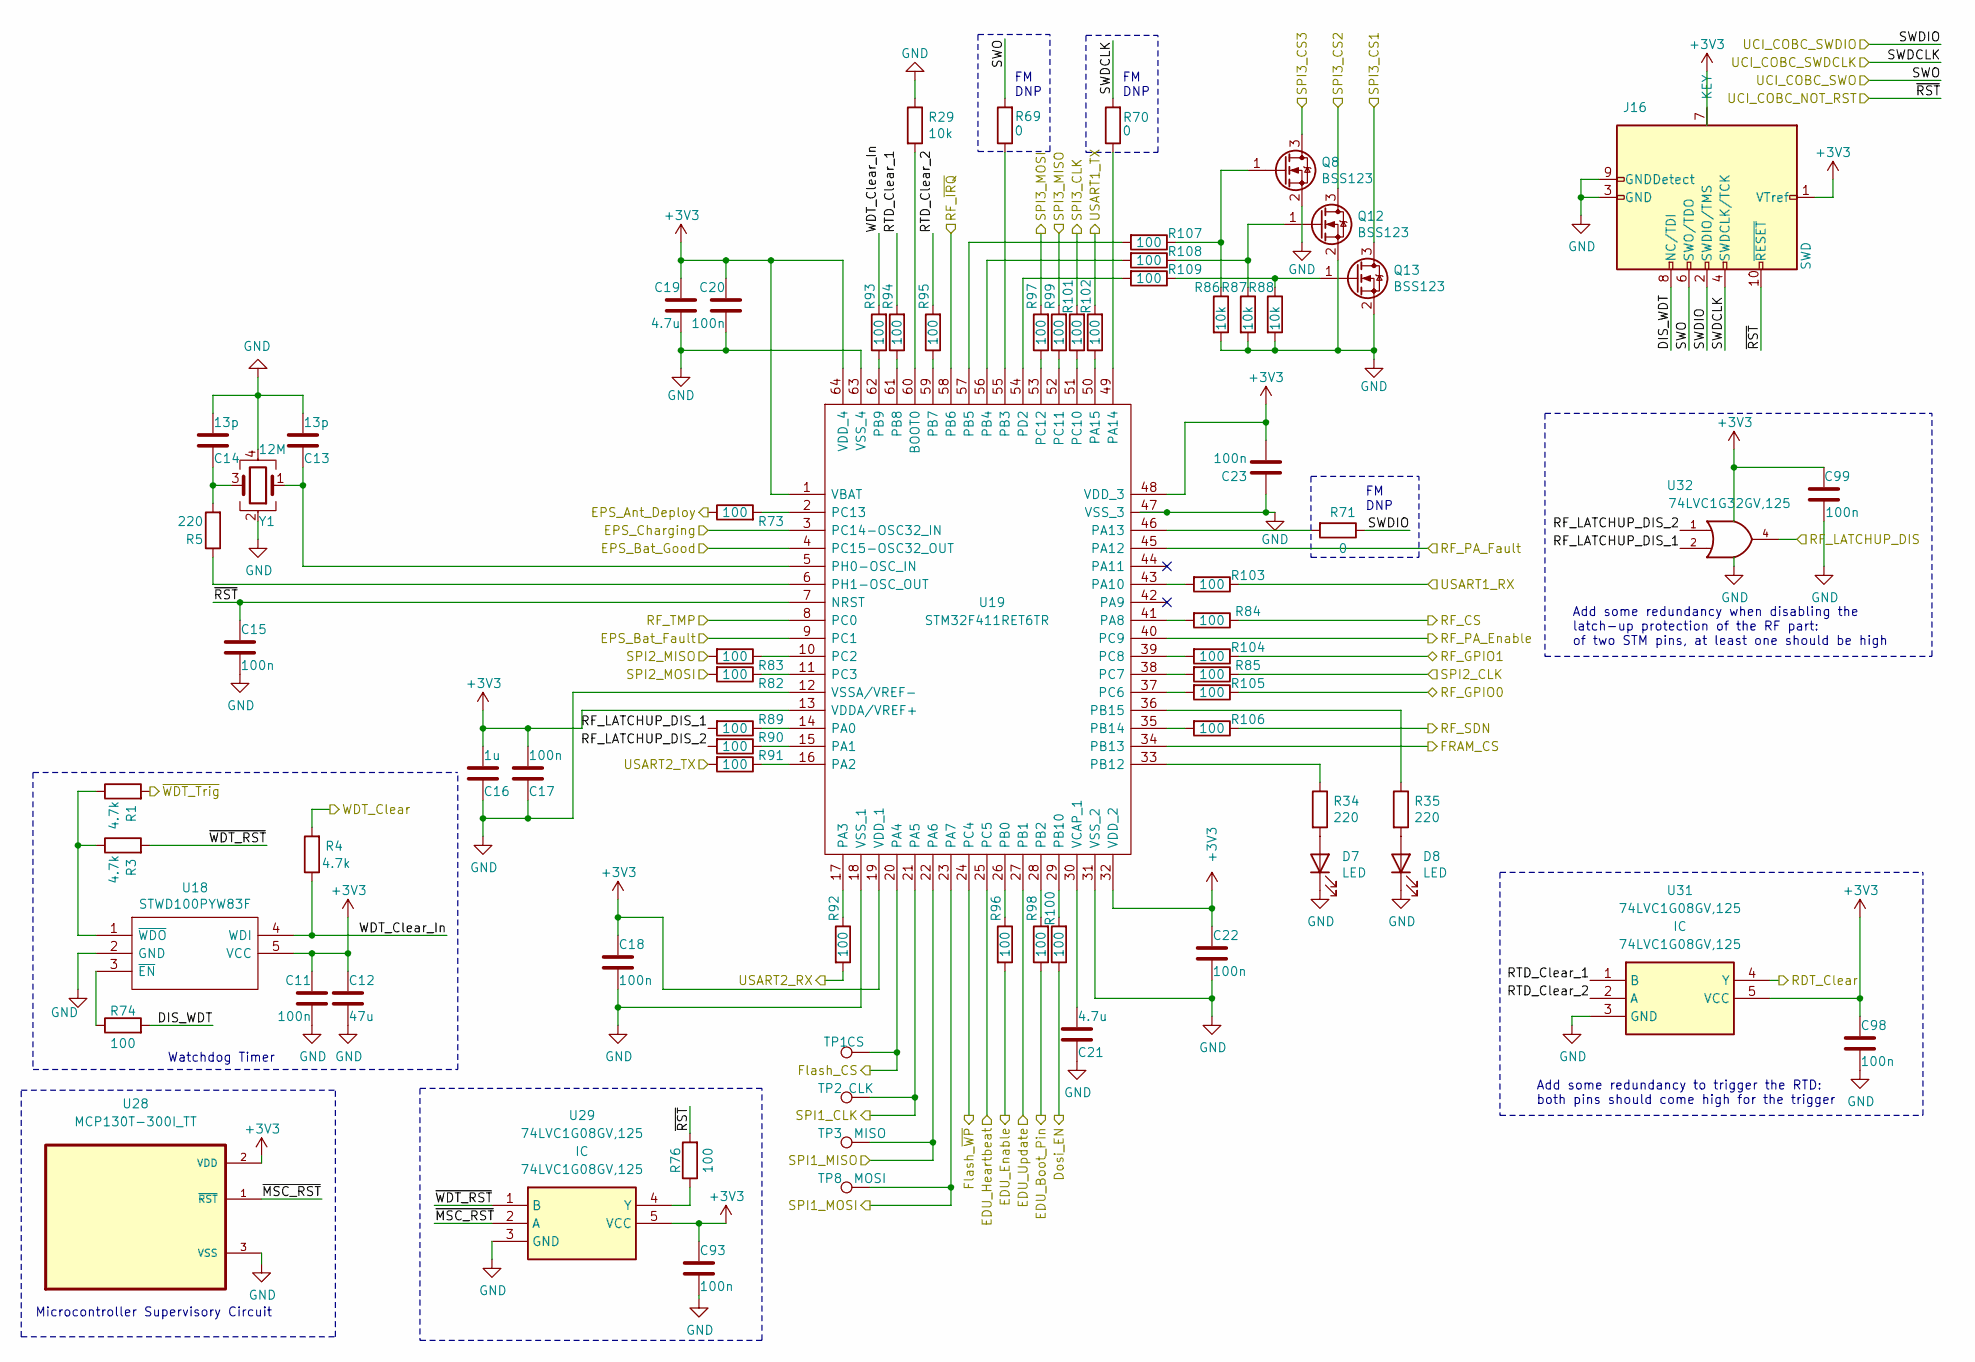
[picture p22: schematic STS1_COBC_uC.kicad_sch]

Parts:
C11, C15, C17, C18, C20, C22, C23, C93, C98, C99: 100n; C_0603_1608Metric; Manufacturer_Part_Number C0603C104K5RACAUTO; JLCPCB Part # C129621
C12: 47u; C_0603_1608Metric; Manufacturer_Part_Number CL10A476MQ8QRNC; JLCPCB Part # C730416
C13, C14: 13p; C_0603_1608Metric; Manufacturer_Part_Number CC0603FRNPO9BN130; JLCPCB Part # C519488
C16: 1u; C_0603_1608Metric; Manufacturer_Part_Number CGA3E1X7R1V105KT000N; JLCPCB Part # C342956
C19, C21: 4.7u; C_0603_1608Metric; Manufacturer_Part_Number CGA3E1X5R0J475KT0Y0E; JLCPCB Part # C338087
D7, D8: LED; LED_0805_2012Metric; Manufacturer_Part_Number BL-HGE35A-AV-TRB; JLCPCB Part # C165984
J16: SWD; SAMTEC_FTSH-105-01-X-DH-A; Manufacturer_Part_Number FTSH-105-01-F-DH-A
Q8, Q12, Q13: BSS123; SOT-23; Manufacturer_Part_Number BSS123N H6327; JLCPCB Part # C534594
R1, R3, R4: 4.7k; R_0603_1608Metric; Manufacturer_Part_Number ERJ-H3EF4701V; JLCPCB Part # C4343266
R5, R34, R35: 220; R_0603_1608Metric; Manufacturer_Part_Number ERJ-H3EF2200V; JLCPCB Part # C4257599
R29, R86, R87, R88: 10k; R_0603_1608Metric; Manufacturer_Part_Number ERJ-H3EF1002V; JLCPCB Part # C4297913
R69, R70, R71: 0; R_0603_1608Metric; Manufacturer_Part_Number ERJ-H3G0R00V; JLCPCB Part # C4117710
R73, R74, R76, R82, R83, R84, R85, R89, R90, R91, R92, R93, R94, R95, R96, R97, R98, R99, R100, R101, R102, R103, R104, R105, R106, R107, R108, R109: 100; R_0603_1608Metric; Manufacturer_Part_Number CRS0603AFX-1000ELF; JLCPCB Part # C2074896
TP1: CS; STS1_Testpoint
TP2: CLK; STS1_Testpoint
TP3: MISO; STS1_Testpoint
TP8: MOSI; STS1_Testpoint
U18: STWD100PYW83F; SOT65P210X110-5N; Manufacturer_Part_Number STWD100PYW83F; JLCPCB Part # C155589
U19: STM32F411RET6TR; QFP50P1200X1200X160-64N; Manufacturer_Part_Number STM32F411RET6TR; Mouser Part Number 511-STM32F411RET6TR
U28: MCP130T-300I_TT; SOT-23-3; Manufacturer_Part_Number MCP130T-300I/TT; JLCPCB Part # C410526
U29, U31: 74LVC1G08GV,125; SOT95P275X110-5N; Mouser Part Number 771-74LVC1G08GV
U32: 74LVC1G32GV,125; SOT95P275X110-5N; Manufacturer_Part_Number 74LVC1G32GV,125; JLCPCB Part # C12517
Y1: 12M; Crystal_SMD_5032-4Pin_5.0x3.2mm; Manufacturer_Part_Number 405C35B12M00000; JLCPCB Part # C1986181

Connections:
+3V3: C11.1, C12.1, C16.1, C17.2, C18.2, C19.2, C20.2, C22.1, C23.1, C93.2, C98.2, C99.1, J16.1 (VTref), J16.7 (KEY), U18.5 (VCC), U19.1 (VBAT), U19.13 (VDDA/VREF+), U19.19 (VDD_1), U19.32 (VDD_2), U19.48 (VDD_3), U19.64 (VDD_4), U28.2 (VDD), U29.5 (VCC), U31.5 (VCC), U32.5 (VCC); also elsewhere on the board
/COBC STM/DIS_WDT: J16.8 (NC/TDI), R74.2
/COBC STM/RF_LATCHUP_DIS_1: R89.2, U32.2
/COBC STM/RF_LATCHUP_DIS_2: R90.2, U32.1
/COBC STM/RTD_Clear_1: R94.2, U31.1 (B)
/COBC STM/RTD_Clear_2: R95.2, U31.2 (A)
/COBC STM/WDT_Clear_In: R4.1, R93.2, U18.4 (WDI)
/COBC STM/~MSC_RST: U28.1 (~RST), U29.2 (A)
/COBC STM/~WDT_RST: R3.2, U29.1 (B)
/Dosi_EN: R100.1; also elsewhere on the board
/EDU_Boot_Pin: R98.1; also elsewhere on the board
/EDU_Enable: R96.2; also elsewhere on the board
/EDU_Heartbeat: U19.25 (PC5); also elsewhere on the board
/EDU_Update: U19.27 (PB1); also elsewhere on the board
/EPS_Ant_Deploy: R73.1; also elsewhere on the board
/EPS_Bat_Fault: U19.9 (PC1); also elsewhere on the board
/EPS_Bat_Good: U19.4 (PC15-OSC32_OUT); also elsewhere on the board
/EPS_Charging: U19.3 (PC14-OSC32_IN); also elsewhere on the board
/FRAM_CS: U19.34 (PB13); also elsewhere on the board
/Flash_CLK: TP2.1 (1_1), U19.21 (PA5); also elsewhere on the board
/Flash_CS: TP1.1 (1_1), U19.20 (PA4); also elsewhere on the board
/Flash_MISO: TP3.1 (1_1), U19.22 (PA6); also elsewhere on the board
/Flash_MOSI: TP8.1 (1_1), U19.23 (PA7); also elsewhere on the board
/Flash_~WP: U19.24 (PC4); also elsewhere on the board
/RDT_Clear: U31.4 (Y); also elsewhere on the board
/RF_CLK: R85.1; also elsewhere on the board
/RF_CS: R84.1; also elsewhere on the board
/RF_GPIO0: R105.1; also elsewhere on the board
/RF_GPIO1: R104.1; also elsewhere on the board
/RF_LATCHUP_DIS: U32.4; also elsewhere on the board
/RF_MISO: R83.2; also elsewhere on the board
/RF_MOSI: R82.2; also elsewhere on the board
/RF_PA_Enable: U19.40 (PC9); also elsewhere on the board
/RF_PA_Fault: U19.45 (PA12); also elsewhere on the board
/RF_SDN: R106.1; also elsewhere on the board
/RF_TMP: U19.8 (PC0); also elsewhere on the board
/RF_~IRQ: U19.58 (PB6); also elsewhere on the board
/STS1_connector/EDU_UART.RX: R103.1; also elsewhere on the board
/STS1_connector/EDU_UART.TX: R102.2; also elsewhere on the board
/STS1_connector/EPS_SPI.CLK: R101.2; also elsewhere on the board
/STS1_connector/EPS_SPI.CS1: Q13.3 (D); also elsewhere on the board
/STS1_connector/EPS_SPI.CS2: Q12.3 (D); also elsewhere on the board
/STS1_connector/EPS_SPI.CS3: Q8.3 (D); also elsewhere on the board
/STS1_connector/EPS_SPI.MISO: R99.2; also elsewhere on the board
/STS1_connector/EPS_SPI.MOSI: R97.2; also elsewhere on the board
/STS1_connector/UCI_COBC.SWDCLK: J16.4 (SWDCLK/TCK), R70.2; also elsewhere on the board
/STS1_connector/UCI_COBC.SWDIO: J16.2 (SWDIO/TMS), R71.1; also elsewhere on the board
/STS1_connector/UCI_COBC.SWO: J16.6 (SWO/TDO), R69.2; also elsewhere on the board
/STS1_connector/UCI_COBC.~RST: C15.2, J16.10 (~RESET), R76.2, U19.7 (NRST); also elsewhere on the board
/STS1_connector/UCI_UART.RX: R92.2; also elsewhere on the board
/STS1_connector/UCI_UART.TX: R91.2; also elsewhere on the board
/WDT_Clear: R4.2; also elsewhere on the board
/~WDT_Trig: R1.2; also elsewhere on the board
GND: C11.2, C12.2, C13.1, C14.1, C15.1, C16.2, C17.1, C18.1, C19.1, C20.1, C21.2, C22.2, C23.2, C93.1, C98.1, C99.2, D7.1 (K), D8.1 (K), J16.3 (GND), J16.5 (GND), J16.9 (GNDDetect), Q8.2 (S), Q12.2 (S), Q13.2 (S), R29.1, R86.2, R87.2, R88.2, U18.2 (GND), U19.12 (VSSA/VREF-), U19.18 (VSS_1), U19.31 (VSS_2), U19.47 (VSS_3), U19.63 (VSS_4), U28.3 (VSS), U29.3 (GND), U31.3 (GND), U32.3 (GND), Y1.2, Y1.4; also elsewhere on the board
unnamed: C14.2, R5.2, Y1.3
unnamed: D7.2 (A), R34.2
unnamed: D8.2 (A), R35.2
unnamed: Q8.1 (G), R86.1, R107.1
unnamed: Q12.1 (G), R87.1, R108.1
unnamed: Q13.1 (G), R88.1, R109.1
unnamed: R74.1, U18.3 (~EN)
unnamed: R1.1, R3.1, U18.1 (~WDO)
unnamed: R29.2, U19.60 (BOOT0)
unnamed: R89.1, U19.14 (PA0)
unnamed: R90.1, U19.15 (PA1)
unnamed: R91.1, U19.16 (PA2)
unnamed: R92.1, U19.17 (PA3)
unnamed: R84.2, U19.41 (PA8)
unnamed: R103.2, U19.43 (PA10)
unnamed: R71.2, U19.46 (PA13)
unnamed: R70.1, U19.49 (PA14)
unnamed: R102.1, U19.50 (PA15)
unnamed: R96.1, U19.26 (PB0)
unnamed: R98.2, U19.28 (PB2)
unnamed: R69.1, U19.55 (PB3)
unnamed: R108.2, U19.56 (PB4)
unnamed: R107.2, U19.57 (PB5)
unnamed: R95.1, U19.59 (PB7)
unnamed: R94.1, U19.61 (PB8)
unnamed: R93.1, U19.62 (PB9)
unnamed: R100.2, U19.29 (PB10)
unnamed: R34.1, U19.33 (PB12)
unnamed: R106.2, U19.35 (PB14)
unnamed: R35.1, U19.36 (PB15)
unnamed: R83.1, U19.10 (PC2)
unnamed: R82.1, U19.11 (PC3)
unnamed: R105.2, U19.37 (PC6)
unnamed: R85.2, U19.38 (PC7)
unnamed: R104.2, U19.39 (PC8)
unnamed: R101.1, U19.51 (PC10)
unnamed: R99.1, U19.52 (PC11)
unnamed: R97.1, U19.53 (PC12)
unnamed: R73.2, U19.2 (PC13)
unnamed: R109.2, U19.54 (PD2)
unnamed: C13.2, U19.5 (PH0-OSC_IN), Y1.1
unnamed: R5.1, U19.6 (PH1-OSC_OUT)
unnamed: C21.1, U19.30 (VCAP_1)
unnamed: R76.1, U29.4 (Y)

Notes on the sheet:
Add some redundancy to trigger the RTD: both pins should come high for the trigger
Microcontroller Supervisory Circuit
FM DNP
Add some redundancy when disabling the latch-up protection of the RF part: of two STM pins, at least one should be high
Watchdog Timer

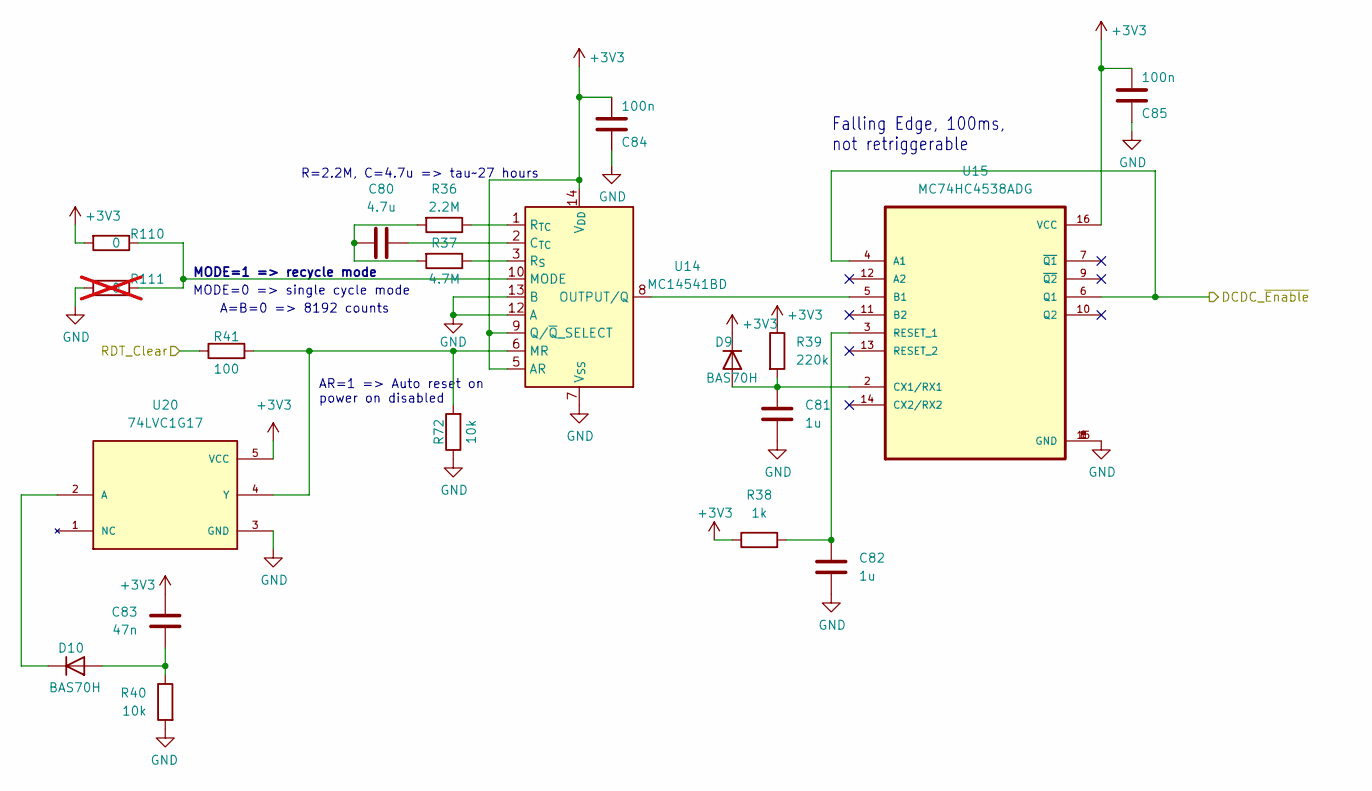
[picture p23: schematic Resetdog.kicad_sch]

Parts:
C80: 4.7u; C_0603_1608Metric; Manufacturer_Part_Number CGA3E1X5R0J475KT0Y0E; JLCPCB Part # C338087
C81, C82: 1u; C_0603_1608Metric; Manufacturer_Part_Number CGA3E1X7R1V105KT000N; JLCPCB Part # C342956
C83: 47n; C_0603_1608Metric; Manufacturer_Part_Number C0603C473K5RACAUTO; JLCPCB Part # C129629
C84, C85: 100n; C_0603_1608Metric; Manufacturer_Part_Number C0603C104K5RACAUTO; JLCPCB Part # C129621
D9, D10: BAS70H; D_SOD-123F; Manufacturer_Part_Number BAS70H,115; JLCPCB Part # C426766
R36: 2.2M; R_0603_1608Metric; Manufacturer_Part_Number ESR03EZPF2204; JLCPCB Part # C2103911
R37: 4.7M; R_0603_1608Metric; Manufacturer_Part_Number ESR03EZPF4704; JLCPCB Part # C2103209
R38: 1k; R_0603_1608Metric; Manufacturer_Part_Number ERJ-H3EF1001V; JLCPCB Part # C4073186
R39: 220k; R_0603_1608Metric; Manufacturer_Part_Number ERJ-H3EF5102V; JLCPCB Part # C4285297
R40, R72: 10k; R_0603_1608Metric; Manufacturer_Part_Number ERJ-H3EF1002V; JLCPCB Part # C4297913
R41: 100; R_0603_1608Metric; Manufacturer_Part_Number CRS0603AFX-1000ELF; JLCPCB Part # C2074896
R110: 0; R_0603_1608Metric; Manufacturer_Part_Number ERJ-H3G0R00V; JLCPCB Part # C4117710
R111: 0; R_0603_1608Metric; Manufacturer_Part_Number ERJ-H3G0R00V; JLCPCB Part # C4117710; not fitted
U14: MC14541BD; SOIC-14_3.9x8.7mm_P1.27mm; Manufacturer_Part_Number MC14541BDR2G; JLCPCB Part # C7292
U15: MC74HC4538ADG; SOIC127P600X175-16N; Manufacturer_Part_Number MC74HC4538ADG; JLCPCB Part # C233613
U20: 74LVC1G17; SOT-23-5; Manufacturer_Part_Number SN74LVC1G17DBVRE4; JLCPCB Part # C3753751

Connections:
+3V3: C83.1, C84.2, C85.2, D9.1 (K), R38.1, R39.1, R110.2, U14.5 (AR), U14.9 (Q/~Q_SELECT), U14.14 (V_{DD}), U15.16 (VCC), U20.5 (VCC); also elsewhere on the board
/DCDC_~Enable: U15.4 (A1), U15.6 (Q1); also elsewhere on the board
/RDT_Clear: R41.1; also elsewhere on the board
GND: C81.2, C82.2, C84.1, C85.1, R40.2, R72.1, R111.2, U14.7 (V_{SS}), U14.12 (A), U14.13 (B), U15.1 (GND), U15.8 (GND), U15.15 (GND), U20.3 (GND); also elsewhere on the board
unnamed: C80.1, R36.2, R37.2
unnamed: C81.1, D9.2 (A), R39.2, U15.2 (CX1/RX1)
unnamed: C83.2, D10.2 (A), R40.1
unnamed: D10.1 (K), U20.2 (A)
unnamed: C80.2, U14.2 (C_{TC})
unnamed: R110.1, R111.1, U14.10 (MODE)
unnamed: R41.2, R72.2, U14.6 (MR), U20.4 (Y)
unnamed: U14.8 (OUTPUT/Q), U15.5 (B1)
unnamed: R37.1, U14.3 (R_{S})
unnamed: R36.1, U14.1 (R_{TC})
unnamed: C82.1, R38.2, U15.3 (RESET_1)

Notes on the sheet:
R=2.2M, C=4.7u => tau~27 hours
Falling Edge, 100ms, not retriggerable
MODE=0 => single cycle mode
A=B=0 => 8192 counts
AR=1 => Auto reset on power on disabled
MODE=1 => recycle mode

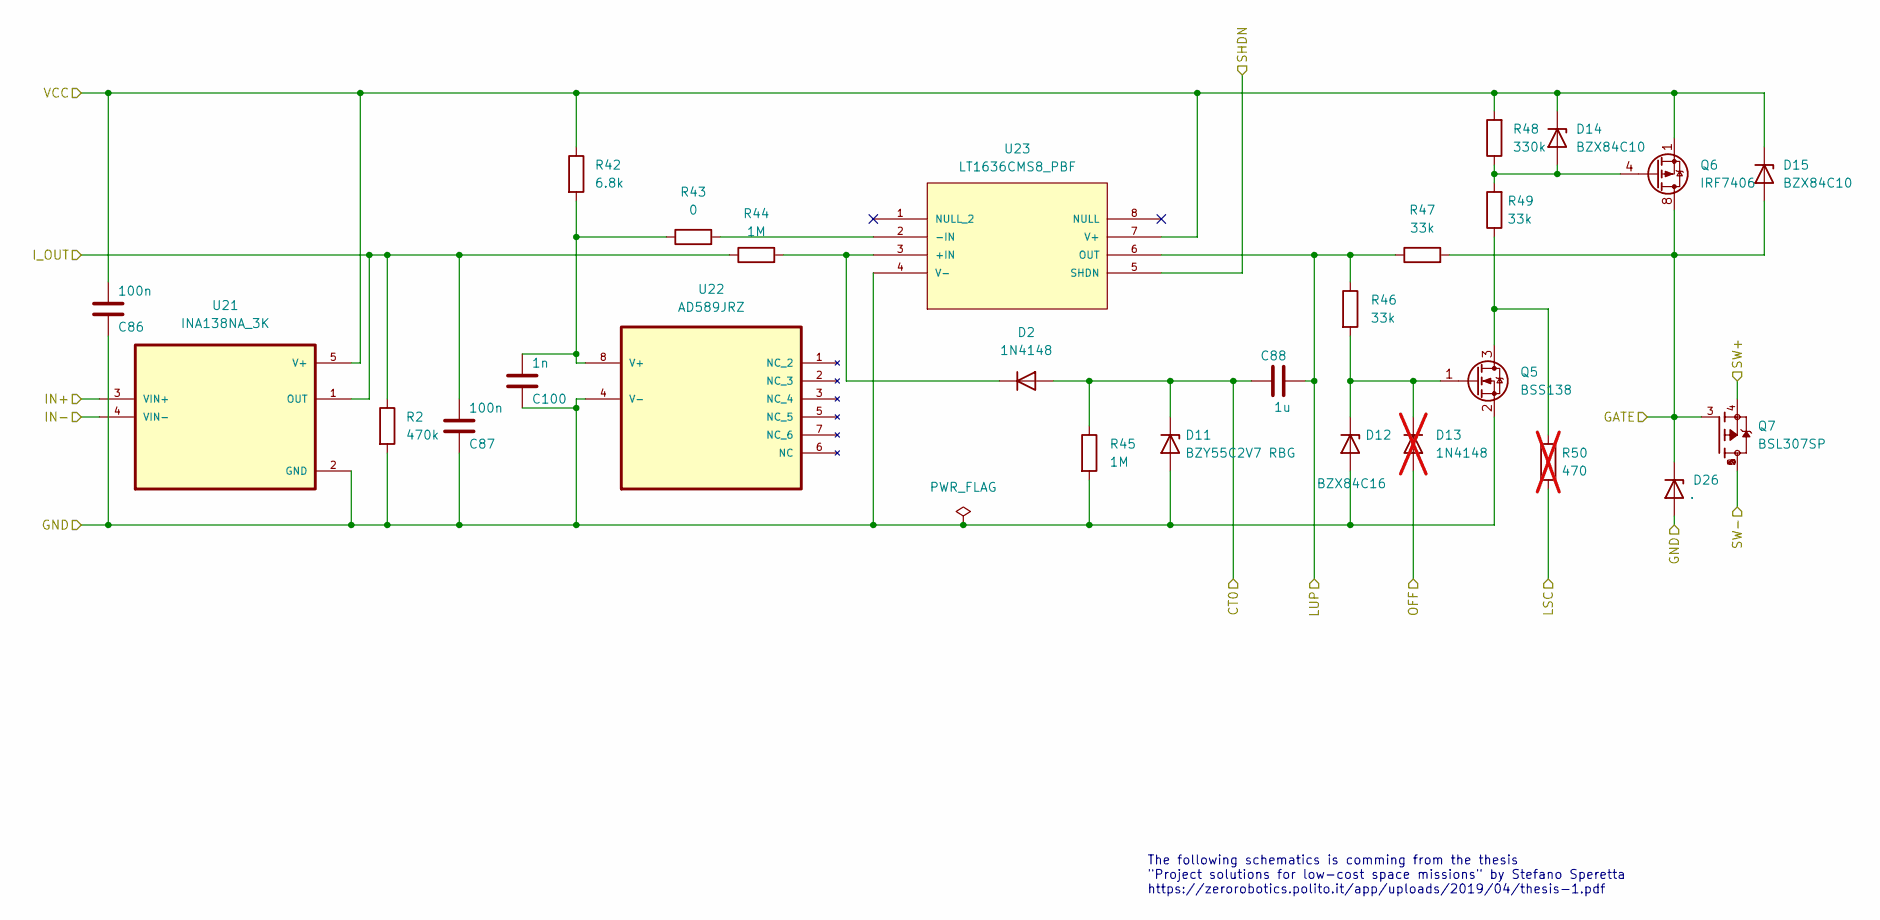
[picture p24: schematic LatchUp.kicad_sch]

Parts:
C86, C87: 100n; C_0603_1608Metric; Manufacturer_Part_Number C0603C104K5RACAUTO; JLCPCB Part # C129621
C88: 1u; C_0603_1608Metric; Manufacturer_Part_Number CGA3E1X7R1V105KT000N; JLCPCB Part # C342956
C100: 1n; C_0603_1608Metric; Manufacturer_Part_Number C0603C102K5RACAUTO; JLCPCB Part # C141069
D2: 1N4148; D_SOD-123; Manufacturer_Part_Number 1N4148W-7-F; JLCPCB Part # C83528
D11: BZY55C2V7 RBG; D_0805_2012Metric; Manufacturer_Part_Number BZY55B2V7 RBG
D12: BZX84C16; SOT-23; Manufacturer_Part_Number BZX84-C16,215; JLCPCB Part # C131660
D13: 1N4148; D_SOD-123; Manufacturer_Part_Number 1N4148W-7-F; JLCPCB Part # C83528; not fitted
D14, D15: BZX84C10; SOT-23; Manufacturer_Part_Number BZX84-C10,235; JLCPCB Part # C550933
D26: PTVS5V0S1UR,115; D_SOD-123; Manufacturer_Part_Number PTVS5V0S1UR,115; JLCPCB Part # C478011
Q5: BSS138; SOT-23; Manufacturer_Part_Number BSS138; JLCPCB Part # C52895
Q6: IRF7406; SOIC-8_3.9x4.9mm_P1.27mm; Manufacturer_Part_Number IRF7406TRPBF; JLCPCB Part # C169769
Q7: BSL307SP; TSOP-6_1.65x3.05mm_P0.95mm; Manufacturer_Part_Number BSL307SP H6327; JLCPCB Part # C534457
R2: 470k; R_0603_1608Metric; Manufacturer_Part_Number MR06X4703FTL; JLCPCB Part # C327839
R42: 6.8k; R_0603_1608Metric
R43: 0; R_0603_1608Metric; Manufacturer_Part_Number ERJ-H3G0R00V; JLCPCB Part # C4117710
R44, R45: 1M; R_0603_1608Metric; Manufacturer_Part_Number MR06X1004FTL
R46, R47, R49: 33k; R_0603_1608Metric; Manufacturer_Part_Number ERJ-H3EF3302V; JLCPCB Part # C4220470
R48: 330k; R_0603_1608Metric; Manufacturer_Part_Number MR06X3303FTL
R50: 470; R_0603_1608Metric; not fitted
U21: INA138NA_3K; SOT-23-5; Manufacturer_Part_Number INA138NA/3K; JLCPCB Part # C47914
U22: AD589JRZ; SOIC-8_3.9x4.9mm_P1.27mm; MPN AD589JRZ; JLCPCB Part # C207416
U23: LT1636CMS8_PBF; MSOP-8_3x3mm_P0.65mm; Manufacturer_Part_Number LT1636CMS8#PBF; DIGIKEY_PART_NUMBER LT1636CMS8#PBFND

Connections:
+5V: C86.2, D14.3 (K), D15.3 (K), Q6.1 (S), Q6.2 (S), Q6.3 (S), R42.1, R48.2, U21.3 (VIN+), U21.5 (V+), U23.7 (V+); also elsewhere on the board
/COBC VR/Latch Up1/CT0: C88.2, D2.2 (A), D11.1 (K), R45.1
/COBC VR/Latch Up1/GATE: D15.1 (A), D26.1 (K), Q6.5 (D), Q6.6 (D), Q6.7 (D), Q6.8 (D), Q7.3, R47.2; also elsewhere on the board
/COBC VR/Latch Up1/IN-: Q7.4, U21.4 (VIN-); also elsewhere on the board
/COBC VR/Latch Up1/I_OUT: C87.2, R2.1, R44.1, U21.1 (OUT); also elsewhere on the board
/COBC VR/Latch Up1/LUP: C88.1, R46.1, R47.1, U23.6 (OUT); also elsewhere on the board
/COBC VR/Latch Up1/SW-: Q7.1, Q7.2, Q7.5, Q7.6; also elsewhere on the board
/RF_LATCHUP_DIS: U23.5 (SHDN); also elsewhere on the board
GND: C86.1, C87.1, C100.1, D11.2 (A), D12.1 (A), D26.2 (A), Q5.2 (S), R2.2, R45.2, U21.2 (GND), U22.4 (V-), U23.4 (V-); also elsewhere on the board
unnamed: D2.1 (K), R44.2, U23.3 (+IN)
unnamed: D12.3 (K), Q5.1 (G), R46.2
unnamed: D14.1 (A), Q6.4 (G), R48.1, R49.2
unnamed: Q5.3 (D), R49.1
unnamed: C100.2, R42.2, R43.1, U22.8 (V+)
unnamed: R43.2, U23.2 (-IN)

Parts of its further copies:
C90, C91: 100n; C_0603_1608Metric; Manufacturer_Part_Number C0603C104K5RACAUTO; JLCPCB Part # C129621
C92: 1u; C_0603_1608Metric; Manufacturer_Part_Number CGA3E1X7R1V105KT000N; JLCPCB Part # C342956
C101: 1n; C_0603_1608Metric; Manufacturer_Part_Number C0603C102K5RACAUTO; JLCPCB Part # C141069
D17: 1N4148; D_SOD-123; Manufacturer_Part_Number 1N4148W-7-F; JLCPCB Part # C83528
D18: BZY55C2V7 RBG; D_0805_2012Metric; Manufacturer_Part_Number BZY55B2V7 RBG
D19: BZX84C16; SOT-23; Manufacturer_Part_Number BZX84-C16,215; JLCPCB Part # C131660
D21, D22: BZX84C10; SOT-23; Manufacturer_Part_Number BZX84-C10,235; JLCPCB Part # C550933
D28: PTVS5V0S1UR,115; D_SOD-123; Manufacturer_Part_Number PTVS5V0S1UR,115; JLCPCB Part # C478011
Q9: BSS138; SOT-23; Manufacturer_Part_Number BSS138; JLCPCB Part # C52895
Q10: IRF7406; SOIC-8_3.9x4.9mm_P1.27mm; Manufacturer_Part_Number IRF7406TRPBF; JLCPCB Part # C169769
Q11: BSL307SP; TSOP-6_1.65x3.05mm_P0.95mm; Manufacturer_Part_Number BSL307SP H6327; JLCPCB Part # C534457
R59: 470k; R_0603_1608Metric; Manufacturer_Part_Number MR06X4703FTL; JLCPCB Part # C327839
R60: 6.8k; R_0603_1608Metric
R61: 0; R_0603_1608Metric; Manufacturer_Part_Number ERJ-H3G0R00V; JLCPCB Part # C4117710
R62, R63: 1M; R_0603_1608Metric; Manufacturer_Part_Number MR06X1004FTL
R64, R65, R67: 33k; R_0603_1608Metric; Manufacturer_Part_Number ERJ-H3EF3302V; JLCPCB Part # C4220470
R66: 330k; R_0603_1608Metric; Manufacturer_Part_Number MR06X3303FTL
U25: INA138NA_3K; SOT-23-5; Manufacturer_Part_Number INA138NA/3K; JLCPCB Part # C47914
U26: AD589JRZ; SOIC-8_3.9x4.9mm_P1.27mm; MPN AD589JRZ; JLCPCB Part # C207416
U27: LT1636CMS8_PBF; MSOP-8_3x3mm_P0.65mm; Manufacturer_Part_Number LT1636CMS8#PBF; DIGIKEY_PART_NUMBER LT1636CMS8#PBFND

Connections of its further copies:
+5V: C90.2, D21.3 (K), D22.3 (K), Q10.1 (S), Q10.2 (S), Q10.3 (S), R60.1, R66.2, U25.3 (VIN+), U25.5 (V+), U27.7 (V+); also elsewhere on the board
/COBC VR/Latch Up/CT0: C92.2, D17.2 (A), D18.1 (K), R63.1
/COBC VR/Latch Up/GATE: D22.1 (A), D28.1 (K), Q10.5 (D), Q10.6 (D), Q10.7 (D), Q10.8 (D), Q11.3, R65.2; also elsewhere on the board
/COBC VR/Latch Up/IN-: Q11.4, U25.4 (VIN-); also elsewhere on the board
/COBC VR/Latch Up/I_OUT: C91.2, R59.1, R62.1, U25.1 (OUT); also elsewhere on the board
/COBC VR/Latch Up/LUP: C92.1, R64.1, R65.1, U27.6 (OUT)
/COBC VR/Latch Up/SW-: Q11.1, Q11.2, Q11.5, Q11.6; also elsewhere on the board
GND: C90.1, C91.1, C101.1, D18.2 (A), D19.1 (A), D28.2 (A), Q9.2 (S), R59.2, R63.2, U25.2 (GND), U26.4 (V-), U27.4 (V-), U27.5 (SHDN); also elsewhere on the board
unnamed: D17.1 (K), R62.2, U27.3 (+IN)
unnamed: D19.3 (K), Q9.1 (G), R64.2
unnamed: D21.1 (A), Q10.4 (G), R66.1, R67.2
unnamed: Q9.3 (D), R67.1
unnamed: C101.2, R60.2, R61.1, U26.8 (V+)
unnamed: R61.2, U27.2 (-IN)

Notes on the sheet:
The following schematics is comming from the thesis "Project solutions for low-cost space missions" by Stefano Speretta https://zerorobotics.polito.it/app/uploads/2019/04/thesis-1.pdf

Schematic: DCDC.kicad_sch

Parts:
C36: 100u; CP_EIA-7343-43_Kemet-X; Voltage 24V; Manufacturer_Part_Number T491X107M025AT; JLCPCB Part # C127835
C37: 22u; C_0603_1608Metric; Voltage 24V; Manufacturer_Part_Number CL10A226MO7JZNC; JLCPCB Part # C2762594
C38, C42, C43, C44: 100n; C_0603_1608Metric; Manufacturer_Part_Number C0603C104K5RACAUTO; JLCPCB Part # C129621
C39: 1u; C_0603_1608Metric; Voltage 24V; Manufacturer_Part_Number CGA3E1X7R1V105KT000N; JLCPCB Part # C342956
C40: 1u; C_0603_1608Metric; Voltage 10V; Manufacturer_Part_Number CGA3E1X7R1V105KT000N; JLCPCB Part # C342956
C41: 22n; C_0603_1608Metric; Manufacturer_Part_Number C0603C223K5RACAUTO; JLCPCB Part # C561824
C45, C46: 10u; C_0603_1608Metric; Voltage 10V; Manufacturer_Part_Number GRM188Z71A106KA73D; JLCPCB Part # C2959727
C47: 100u; CP_EIA-7343-43_Kemet-X; Voltage 5V; Manufacturer_Part_Number T491X107M025AT; JLCPCB Part # C127835
C79: 1u; C_0603_1608Metric; Manufacturer_Part_Number CGA3E1X7R1V105KT000N; JLCPCB Part # C342956
C95: 4.7u; C_0603_1608Metric; Manufacturer_Part_Number CGA3E1X5R0J475KT0Y0E; JLCPCB Part # C338087
D1: UCLAMP0871P.TNT; SGP1610N2; Manufacturer_Part_Number UCLAMP0871P.TNT; JLCPCB Part # C1975697
D4: AQ1003-01LTG; D_SOD-523; Manufacturer_Part_Number AQ1003-01LTG; JLCPCB Part # C3702224
D27: PTVS5V0S1UR,115; D_SOD-123; Manufacturer_Part_Number PTVS5V0S1UR,115; JLCPCB Part # C478011
L2: 4.7u; L_12x12mm_H6mm; PartNumber 7447706047; JLCPCB Part # C1858253
Q2: BSS123; SOT-23; Manufacturer_Part_Number BSS123N H6327; JLCPCB Part # C534594
R14: 100; R_0603_1608Metric; Manufacturer_Part_Number CRS0603AFX-1000ELF; JLCPCB Part # C2074896
R15: 1M; R_0603_1608Metric; Manufacturer_Part_Number MR06X1004FTL
R16: 100m; R_0603_1608Metric; Manufacturer_Part_Number RCWL0603R100JQEA; JLCPCB Part # C1698656
R17: 100k; R_0603_1608Metric; Manufacturer_Part_Number ERJ-H3ED1003V; JLCPCB Part # C4217147
R18: 33k; R_0603_1608Metric; Manufacturer_Part_Number ERJ-H3EF3302V; JLCPCB Part # C4220470
R19: 21.5k; R_0603_1608Metric; Manufacturer_Part_Number RT0603FRE0721K5L; JLCPCB Part # C706139
U6: MP28167GQ; MP28167_QFN16; Manufacturer_Part_Number MP28167GQ-P; JLCPCB Part # C3188180

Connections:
+5V: C44.1, C45.1, C46.1, C47.1, D4.1 (K), U6.12 (OUT); also elsewhere on the board
/DCDC_~Enable: R14.2; also elsewhere on the board
GND: C36.2, C37.2, C38.2, C39.2, C40.2, C41.2, C44.2, C45.2, C46.2, C47.2, C79.2, C95.2, D1.2 (A), D4.2 (A), D27.2 (A), Q2.2 (S), R15.2, R18.2, R19.2, U6.2 (GND), U6.4 (NC), U6.5 (RSV1), U6.6 (RSV2), U6.8 (NC), U6.10 (GND), U6.11 (GND); also elsewhere on the board
unnamed: C39.1, R16.2
unnamed: C95.1, D27.1 (K), Q2.1 (G), R14.1, R15.1
unnamed: C79.1, Q2.3 (D), R17.2, R18.1, U6.3 (EN)
unnamed: C42.2, U6.16 (BST1)
unnamed: C43.2, U6.13 (BST2)
unnamed: C41.1, R19.1, U6.7 (OC)
unnamed: C42.1, L2.1, U6.15 (SW1)
unnamed: C43.1, L2.2, U6.14 (SW2)
unnamed: C40.1, U6.9 (VCC)
VBUS: C36.1, C37.1, C38.1, D1.1 (K), R16.1, R17.1, U6.1 (IN); also elsewhere on the board

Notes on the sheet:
Undervoltage Lockout at 3.99V Startup at 4.4V

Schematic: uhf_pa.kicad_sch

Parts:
C67: 50p; C_0402_1005Metric; PartNumber CC0402JRNPO9BN500; JLCPCB Part # C576707
C68: 100n; C_0402_1005Metric; PartNumber CGA2B3X5R1H104K050BB; JLCPCB Part # C2168987
C70, C75, C76: 100p; C_0402_1005Metric; PartNumber CBR04C101J3GAC; JLCPCB Part # C386123
C71: 10u; C_0805_2012Metric; PartNumber EMK212BB7106KG-T; JLCPCB Part # C2182156
C72: 100n; C_0805_2012Metric; Manufacturer_Part_Number C0805C104K1RACAUTO; JLCPCB Part # C141125
C73: 10u; CP_EIA-6032-28_Kemet-C; PartNumber T495C106K035ATE400; JLCPCB Part # C1959557
C74: 1n; C_0805_2012Metric; Manufacturer_Part_Number C0805C102J5RACAUTO; JLCPCB Part # C129636
C77: 33p; C_0402_1005Metric; Manufacturer_Part_Number CL05C330JB5NNNC; JLCPCB Part # C70465
C78: 3.3p; C_0402_1005Metric; PartNumber GJM1555C1H3R3WB01D; JLCPCB Part # C88892
FB1: Ferrite_Bead; L_0603_1608Metric; PartNumber BLM18KG331SN1D; JLCPCB Part # C85832
L14: 4n; L_0402_1005Metric; PartNumber LQW15AN6N0B80D; JLCPCB Part # C2043867
L16: 68n; L_0402_1005Metric; PartNumber LQW15AN68NJ0ZD; JLCPCB Part # C2049784
L17: 18n; L_0805_2012Metric; PartNumber LQW2BAN18NG00L; JLCPCB Part # C2042168
L18: 5.6n; L_0402_1005Metric; PartNumber LQW15AN5N6C1ZD
L19: 47n; L_0402_1005Metric; PartNumber LQW15AN47NJ8ZD; JLCPCB Part # C3222081
R27: 240; R_0603_1608Metric; Manufacturer_Part_Number 0603WAJ0241T5E; JLCPCB Part # C25221
R28: 280; R_0603_1608Metric; Manufacturer_Part_Number RC0603FR-07280RL; JLCPCB Part # C482820
R30, R58: 110k; R_0603_1608Metric; Manufacturer_Part_Number ERJ-H3EF1103V; JLCPCB Part # C4176290
R31: 470; R_0603_1608Metric; Manufacturer_Part_Number ERJ-3EKF4700V; JLCPCB Part # C169259
R112: 100; R_0603_1608Metric; Manufacturer_Part_Number CRS0603AFX-1000ELF; JLCPCB Part # C2074896
TP7: GND; TestPoint_Keystone_5015_Micro_Mini; PartNumber 5015
U12: TPS22950_Q1; TSOT-23-6; PartNumber TPS22950CQDDCRQ1; JLCPCB Part # C17349276
U13: TQP7M9106; QFN-24-1EP_4x4mm_P0.5mm_EP2.7x2.7mm_ThermalVias; PartNumber TQP7M9106; JLCPCB Part # C920265

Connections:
+3.3VP: R58.1; also elsewhere on the board
+5VP: C71.2, U12.2 (VIN); also elsewhere on the board
/COBC_RF/RF_LPF1_Out: C67.2, L14.2; also elsewhere on the board
/COBC_RF/RF_LPF2_In: C78.2; also elsewhere on the board
/COBC_RF/UHF_PA/5V_TX_U: C72.1, C73.1, C74.1, C75.1, FB1.2, R27.1, R28.2, U12.5 (VOUT)
/COBC_RF/UHF_PA/PA_Enable: R30.2, U12.1 (ON); also elsewhere on the board
/COBC_RF/UHF_PA/RF_Amp_In: C67.1, U13.4 (RFIN), U13.5 (RFIN)
/COBC_RF/UHF_PA/RF_Amp_Match1: C77.2, L18.1, L19.1
/COBC_RF/UHF_PA/RF_Amp_Match2: C78.1, L19.2
/COBC_RF/UHF_PA/RF_Amp_Out: C77.1, L17.2, U13.14 (RFOUT/VCC), U13.15 (RFOUT/VCC), U13.16 (RFOUT/VCC)
/RF_PA_Fault: R112.1; also elsewhere on the board
GND: C68.2, C70.2, C71.1, C72.2, C73.2, C74.2, C75.2, C76.1, L14.1, L18.2, R30.1, R31.2, TP7.1 (1_1), U12.3 (GND), U13.2 (GND), U13.3 (GND), U13.6 (GND), U13.7 (GND), U13.8 (GND), U13.9 (GND), U13.10 (GND), U13.11 (GND), U13.12 (GND), U13.13 (GND), U13.17 (GND), U13.19 (GND), U13.20 (GND), U13.21 (GND), U13.22 (GND), U13.23 (GND), U13.24 (GND), U13.25 (EP); also elsewhere on the board
unnamed: C68.1, L16.2, R27.2
unnamed: C76.2, FB1.1, L17.1
unnamed: R58.2, R112.2, U12.6 (FLT)
unnamed: R31.1, U12.4 (ILIM)
unnamed: L16.1, U13.18 (IREF)
unnamed: C70.1, R28.1, U13.1 (VBIAS)

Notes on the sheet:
Current limit: 2.65A ILIM = 1.18 * R^(-1.072)
3.3->ON
5.0->ON (8.9mA)

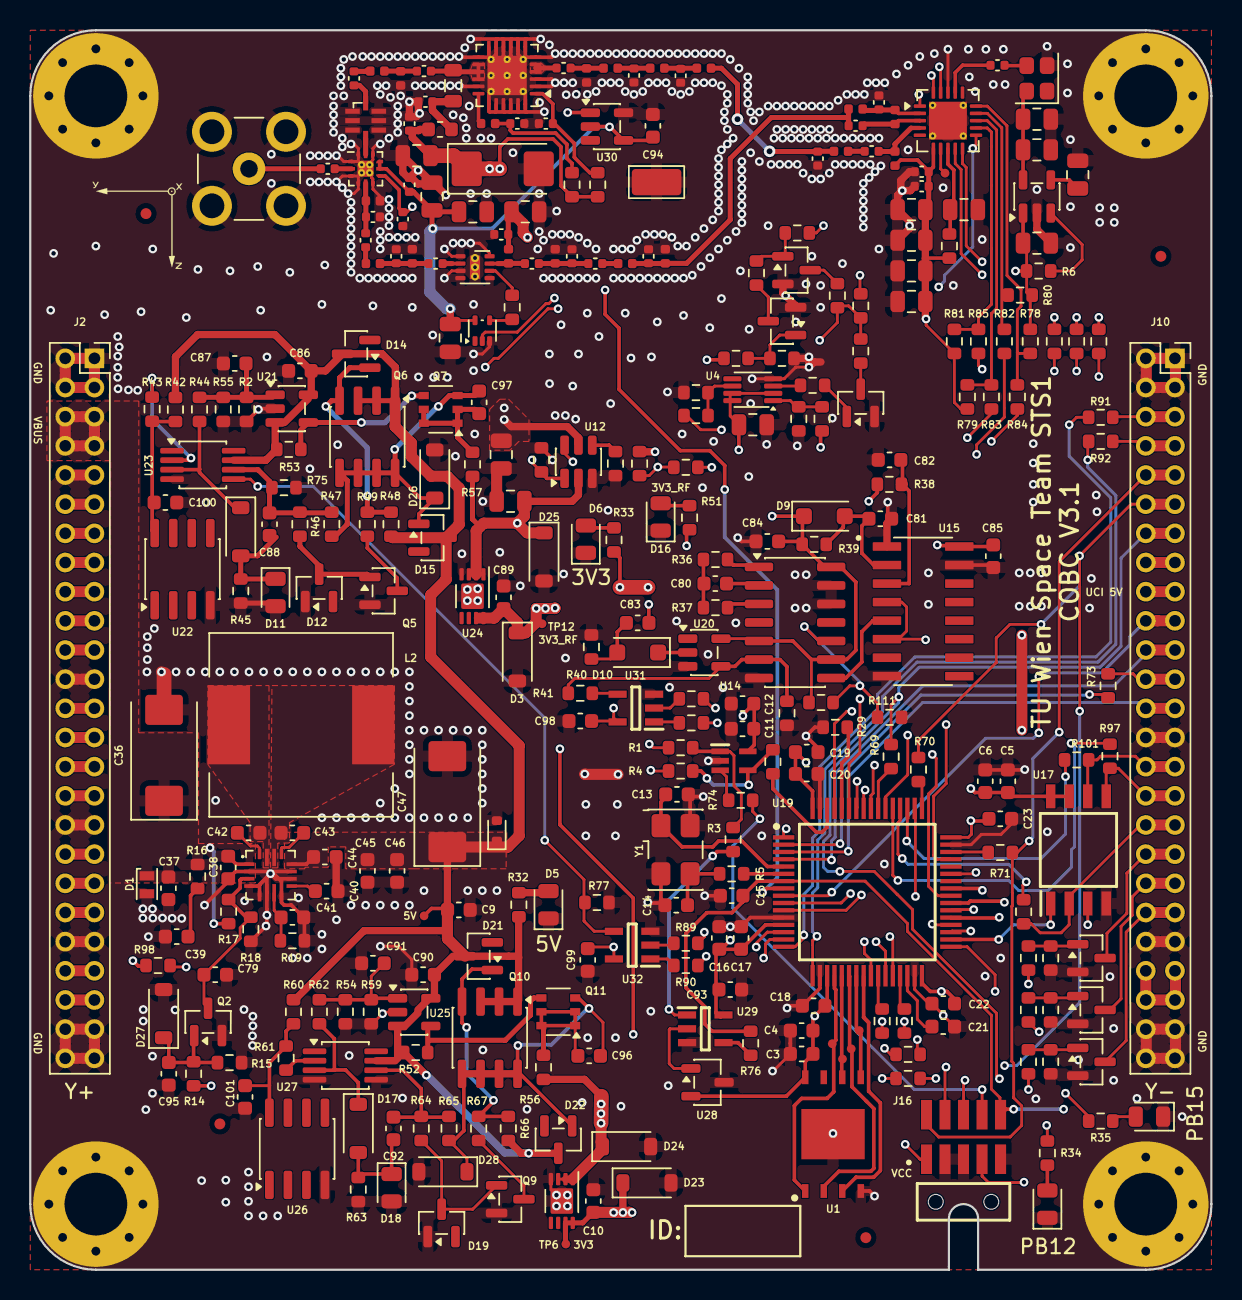
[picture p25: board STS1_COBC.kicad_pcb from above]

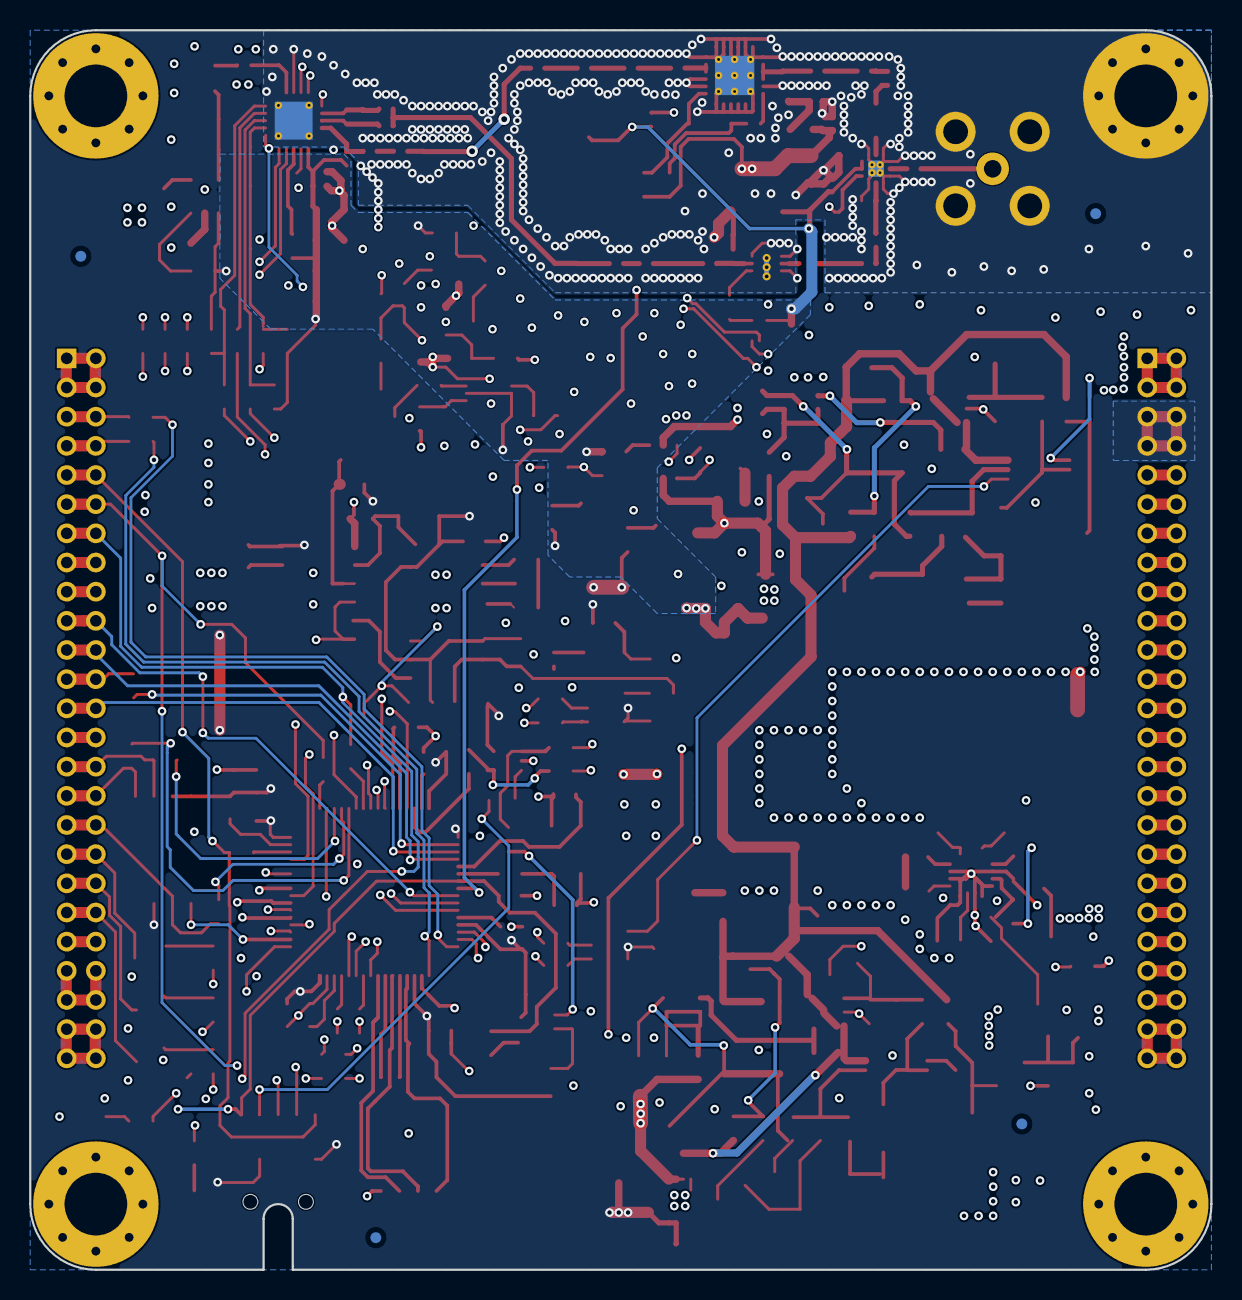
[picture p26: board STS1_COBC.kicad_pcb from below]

Board: 4 copper layers, 81.0 x 85.0 mm, 328 parts (4 on the bottom side), 212 nets.

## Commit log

2021-12-17 Version 1
    Version 1 of the PCBs of the COBC, ordered in 2021.12
    [Connector.sch, DFN8_2x3MC_MCH.step, F27 F30 package 2018.dxf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]
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2022-07-03 more work done
    All parts besides RF added
    [DCDC.kicad_sch, Maxim_22Pin_FC2QFN.step, STS1_COBC_RF.kicad_sch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]
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2023-03-21 Set all passive components (except in the RF path) to 0603
    [DCDC.kicad_sch, STS1_COBC_Memories.kicad_sch, STS1_COBC_V2.kicad_pcb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]
2023-03-21 Add missing C79 capacitor
    [DCDC.kicad_sch, STS1_COBC_V2.kicad_pcb, STS1_COBC_V2.kicad_sch]
2023-05-01 Add resetdog timer (RDT) schematics
    [Resetdog.kicad_sch, STS1_COBC_V2.kicad_sch]
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2023-05-07 Add preliminary resetdog PCB layout.
    [Resetdog.kicad_sch, STS1_COBC_V2.kicad_pcb, STS1_COBC_V2.kicad_sch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]
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2023-05-08 Modify resetdog
    [Resetdog.kicad_sch, STS1_COBC_V2.kicad_pcb, STS1_COBC_V2.kicad_sch]
2023-05-08 Add missing VBUS connection
    [STS1_COBC_V2.kicad_pcb]
2023-05-08 Replace schematics symbol of D9 and D10 diods
    [Resetdog.kicad_sch, STS1_COBC_V2.kicad_pcb, STS1_COBC_V2.kicad_sch]
2023-05-10 Flip D10 to correct orientation
    [STS1_COBC_V2.kicad_pcb]
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2023-05-30 feat: update RF hardware and clean up ERC errors
    [DCDC.kicad_sch, Resetdog.kicad_sch, STS1_COBC.kicad_sch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]
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2023-06-06 feat(RF): better LPF tuning and add part numbers to all inductors
    [DCDC.kicad_sch, STS1_COBC.kicad_sch, STS1_RF.kicad_sch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]
2023-06-08 Add missing 3D models and fix 3D model path issues
    [CY15B108QN-40SXI.stp, F2972NEGK8.stp, FPF2701MPX.stp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]
2023-06-08 Fix labels
    [Resetdog.kicad_sch, STS1_COBC.kicad_sch]
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2023-06-22 Fix footprint assignments: all IC should have U designator
    [STS1_COBC.kicad_sch, STS1_COBC_Memories.kicad_sch, STS1_COBC_uC.kicad_sch]
2023-06-22 Fix footprint assignments: all CSBI headers should have J designator
    [DCDC.kicad_sch, STS1_COBC.kicad_sch, STS1_COBC_Memories.kicad_sch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]
2023-06-22 Exclude jumpers, mounting holes, fiducials etc. from BOM
    [Resetdog.kicad_sch, STS1_COBC.kicad_sch, STS1_COBC_Memories.kicad_sch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]
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2023-06-22 Fix mismatch between footprint and part number for C48, C72, C74, R13, R24, R21, R27, R28, R30, R31
    [STS1_RF.kicad_sch, uhf_pa.kicad_sch]
2023-07-08 Update values of components in the RF subsystem and swap CL instead of LC filter (L14 and C67)
    [STS1_COBC.kicad_sch, STS1_RF.kicad_sch, uhf_pa.kicad_sch]
2023-11-01 Reorganize and clean-up the components around the STM. Pinout changes: 1) Flash_CS moved from PB9 to PA4 2) Dosi_En added on PB10 3) EDU_Boot_Pin added on PB2 4) WDT_Clear moved from PA9 to PB9
    [STS1_COBC.kicad_sch, STS1_COBC_Memories.kicad_sch, STS1_COBC_uC.kicad_sch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]
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2023-11-13 Added 3D models for some components: SMB connector, D1 diode and oscillators
    [STS1_COBC.kicad_pcb]
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2024-03-03 Make changes to the RDT: switch off AR, add Schmidt trigger for MR, change values of R40 and C83
    [Resetdog.kicad_sch, STS1_COBC.kicad_pcb, STS1_COBC.kicad_sch]
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2024-03-16 Add a temperature sensor near RF amplifier chip
    [STS1_COBC.kicad_sch, STS1_COBC_uC.kicad_sch, STS1_RF.kicad_sch]
2024-03-16 Add a delay capacitor to keep DC-DC turned off for some time after ~EN pin is toggled
    [DCDC.kicad_sch, STS1_COBC.kicad_sch]
2024-03-16 Add for new lines to the UCI bus; plus minor fixes: introduce resistor in EDU_BOOT_Pin line, remove zener before DC-DC ~EN input
    [DCDC.kicad_sch, Resetdog.kicad_sch, STS1_COBC.kicad_sch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]
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2024-03-16 Add 3D models for AND gate and FRAM
    [74LVC1G08GV_125.stp]
2024-03-17 Include R14, C95, R15 and Q2 into the bill of materials
    [DCDC.kicad_sch, LatchUp.kicad_sch, Resetdog.kicad_sch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]
2024-03-17 Relocate Q8 mosfet to protect the DC-DC from UCI_COBC_5V input and make 5V traces thicker
    [DCDC.kicad_sch, LatchUp.kicad_sch, Resetdog.kicad_sch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]
2024-03-17 Move DC-DC circuit 2cm down and reposition latch-up circuits
    [DCDC.kicad_sch, LatchUp.kicad_sch, Resetdog.kicad_sch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]
2024-03-20 Change FRAM to the one recommended by Infineon: CY15B108QN-40SXI -> CY15B104Q-SXI
    [STS1_COBC.kicad_sch, STS1_COBC_Memories.kicad_sch]
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2024-06-22 Add manufacture number and JLCPCB part number to components
    [DCDC.kicad_sch, LatchUp.kicad_sch, Resetdog.kicad_sch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]
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2024-06-23 Remove Q8 and add zener diodes to protect output of LDOs and latch-up protection circuits
    [STS1_COBC.kicad_sch, STS1_PowerRegulation.kicad_sch]
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2024-06-23 Add slew-rate control capacitors to latch-up protection circuits
    [Resetdog.kicad_sch, STS1_COBC.kicad_sch, STS1_PowerRegulation.kicad_sch]
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2024-06-24 Fix the issue with WDT intervening the programming cycle: use pins 7 and 9 of JTAG connector to pull ~EN pin of WDT to the high level
    [STS1_COBC.kicad_sch, STS1_COBC_uC.kicad_sch]
2024-07-01 Add a defined state (pulled to GND) of the output of LT1336 for the case when it is a shutdown state
    [LatchUp.kicad_sch, STS1_COBC.kicad_sch, STS1_PowerRegulation.kicad_sch]
2024-07-04 Add some redundancy to trigger the RTD: two STM pins should come high for the trigger event to happen
    [STS1_COBC.kicad_sch, STS1_COBC_uC.kicad_sch]
2024-07-05 Add some redundancy when the latch-up protection of the RF part is disabled: out of two STM pins, at least one should be high
    [STS1_COBC.kicad_sch, STS1_COBC_uC.kicad_sch]
2024-07-06 Add a 3D model of the 74LVC1G32GV_125 chip
    [74LVC1G32GV_125.stp]
2024-07-06 Decouple U29 from the ~RST comming from the JTAG connector
    [STS1_COBC.kicad_sch, STS1_COBC_uC.kicad_sch]
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2024-07-06 Increase inrush current threshold for latch-up protection: C87, C91 22 pF -> 100 nF
    [LatchUp.kicad_sch, STS1_COBC.kicad_sch]
2024-07-06 Make a jump-start pulse for RTD shorter: R40 22 kOhm -> 10 kOhm, C83 10 uF -> 47 nF
    [Resetdog.kicad_sch, STS1_COBC.kicad_sch]
2024-07-07 Adhere to the recommendations from AD589 datasheet: R42, R80 27k -> 6.8k for ~500 uA current and add 1 nF shunt capacitor
    [LatchUp.kicad_sch, STS1_COBC.kicad_sch]
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2024-07-07 Do not populate R69, R70 and R71 on the flight model CSBI-JTAG interface won't be used
    [STS1_COBC_uC.kicad_sch]
2024-07-07 Update the 12 MHz crystal oscillator value and change the related capacitors: C13, C14 20 pF -> 13 pF
    [LatchUp.kicad_sch, STS1_COBC.kicad_sch, STS1_COBC_uC.kicad_sch]
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2024-07-12 Fix power domain crossing issue between RF and STM units
    [LatchUp.kicad_sch, STS1_COBC.kicad_sch, STS1_COBC_uC.kicad_sch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]
2024-07-13 Fix power domain crossing issue between COBC and EPS
    [STS1_COBC.kicad_sch, STS1_COBC_uC.kicad_sch]
2024-07-13 Increase latch-up protection recovery time from ~10 ms to ~100 ms and add some GND vias to connect disconnected parts for In1.Cu layer
    [LatchUp.kicad_sch, STS1_COBC.kicad_sch]
2024-07-13 Increase delay before RTD toggles the DC-DC converter on and off: C95 47 nF -> 4.7 uF
    [DCDC.kicad_sch, STS1_COBC.kicad_sch]
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2024-07-14 Add more series resistors to the outputs of STM and move labels near CSBI to the side of the PCB
    [STS1_COBC.kicad_sch, STS1_COBC_uC.kicad_sch]
2024-07-15 Switch RTD MC14541BD IC from single cycle mode to recycle mode, but leave an option to switch back
    [Resetdog.kicad_sch, STS1_COBC.kicad_sch]
2024-07-23 Update the manufacturer part number for some of components to be compatible with avaiable parts in the JLC parts database
    [DCDC.kicad_sch, LatchUp.kicad_sch, Resetdog.kicad_sch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]
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2024-07-28 Replace the U12 from FPF2702 to TPS22950-Q1: R30 is pulling down, R31: 110K -> 470 Ohm, U7 is removed, since ON is active high now
    [STS1_COBC.kicad_sch, STS1_RF.kicad_sch, uhf_pa.kicad_sch]
2024-07-28 Add a pull-up resistor for FLT pin of U12 and decouple U12 and STM with a series resistor
    [STS1_COBC.kicad_sch, STS1_RF.kicad_sch, uhf_pa.kicad_sch]
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2024-07-28 Replace U11 NL17SV04XV5T2G with 74LVC1G14Z-7 and add MFT number for R31
    [STS1_COBC.kicad_sch, STS1_RF.kicad_sch]
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2024-08-31 Fix bug with footprints of components for R27 and R28: 0402->0603, replace manufacter number and JLCPCB part id.
    [uhf_pa.kicad_sch]
2024-08-31 Exclude R70 and R71 from BOM (they should not be populated on FM).
    [STS1_COBC_uC.kicad_sch]
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2026-04-09 Fix the RF-STM SPI communication issue: reduce the value of R81 from 4.7K to 470 Ohm
    [LatchUp.kicad_sch, Resetdog.kicad_sch, STS1_COBC_uC.kicad_sch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]
2026-04-09 Tweak RF amplifier settings: C77 from 24pF to 33pF, L18 from 8.2nH to 5.6nH
    [uhf_pa.kicad_sch]
2026-04-09 Increase the value of R54 from 220K to 1M to reduce the STM latch-up protection threshold to ~190 mA
    [STS1_PowerRegulation.kicad_sch]
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2026-07-23 fix: use 0805 size inductor for PA power supply and make DRC happy after KiCAD10 upgrade
    [STS1_COBC.kicad_pcb, STS1_COBC.kicad_sch, STS1_RF.kicad_sch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]
2026-08-08 fix: add back the paths for 3D models located in the STSLib directory
    [STS1_COBC.kicad_pcb]
2026-08-08 fix: update coordinate system
    [STS1_COBC.kicad_pcb, STS1_COBC.kicad_sch]

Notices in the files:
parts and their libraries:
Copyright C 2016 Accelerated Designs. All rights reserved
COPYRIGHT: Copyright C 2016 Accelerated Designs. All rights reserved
